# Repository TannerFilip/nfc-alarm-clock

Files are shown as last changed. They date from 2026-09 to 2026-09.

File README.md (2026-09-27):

# NFC-dismiss alarm clock firmware

Milestone 5 development increment: staged PN7160 NCI transport and physical-tag
bring-up. **Production alarms remain gated until the connected reader has passed
the on-device checks below.**
The user confirmed milestone 1 works on-device. Milestone 2 has not been flashed
or physically verified by the agent. The user reports the OLED, encoder/light
sensing and 5% audio test work. The PN7160 board is now connected, but its straps,
VEN/IRQ behavior and NCI communication remain unverified. Milestone 3 builds and
host tests pass; the user reports its development alarm sounded and was dismissed
through the enrolled simulated-tag path on the device.
Milestone 4 builds and host tests pass. The user reports that its QR join and
direct configuration page work, but its remaining persistence/recovery checks
have not been physically observed. Milestone 5 implementation is present; its
host suite and both firmware profiles build successfully. The user reports that
NFC-A reading and explicit physical enrollment now work; remaining results are in
[the validation log](docs/validation.md).

## Build and flash

Pinned SDK: **ESP-IDF v6.1**, commit
`fff9895c82d744c7237be8847347bdd1b07c6643`. No Arduino or external components.
Use Espressif Installation Manager to install v6.1 for ESP32-S3, or the pinned
`.devcontainer` image. In VS Code select that installation with the Espressif
extension, then open an ESP-IDF terminal. Do not use the old root `sdkconfig`:
the original starter targeted ESP32 / 2 MB. Use the isolated build below.

On this workstation the EIM environment can be activated with:

```bash
source /home/tanner/.espressif/tools/activate_idf_v6.1.sh
idf.py --version
```

From the repository root, production profile (simulation disabled):

```bash
idf.py -B build/m1 -D SDKCONFIG=build/m1/sdkconfig build
idf.py -B build/m1 -D SDKCONFIG=build/m1/sdkconfig -p /dev/ttyUSB0 flash monitor
```

Replace `/dev/ttyUSB0` with the USB-to-UART bridge's port; use the DevKit's UART
USB connector. Monitor baud is 115200. Exit monitor with Ctrl+]. If automatic
download fails, hold BOOT, tap RESET, release BOOT, and retry flash. These
commands write bootloader, partition table and application; no erase-flash is
required. Flash only the specified N32R16V module. Do not burn eFuses.

Follow the supplied [hardware power instructions](hardware/breadboard-prototype/README.md):
**disconnect U3 OUT from U1 5V before attaching programming USB**. Remove USB
before reconnecting U3. The boost supply and programming USB must not be connected
to U1 simultaneously under this wiring guide.

Explicit development profile, in a separate configuration/build directory:

```bash
idf.py -B build/m1-dev -D SDKCONFIG=build/m1-dev/sdkconfig -D 'SDKCONFIG_DEFAULTS=sdkconfig.defaults;sdkconfig.development' build
idf.py -B build/m1-dev -D SDKCONFIG=build/m1-dev/sdkconfig -p /dev/ttyUSB0 flash monitor
```

This prints the development/simulation banner on serial and OLED and enables the
Milestone 5 development firmware. The `build/m1` and `build/m1-dev` directory names
are retained for VS Code compatibility; they build the current source.
Never ship the development profile. To use the extension's
Build/Flash buttons instead, the checked-in workspace settings currently select the
development profile: `idf.buildPath` is `${workspaceFolder}/build/m1-dev`, and
`idf.cmakeCompilerArgs` supplies both `-DSDKCONFIG=build/m1-dev/sdkconfig` and
`-DSDKCONFIG_DEFAULTS=sdkconfig.defaults;sdkconfig.development`. Select
the UART port. The CLI commands above are the reference workflow.
These development build settings are already supplied in `.vscode/settings.json`.

## Milestone 5 PN7160 bring-up

Milestone 5 is deliberately staged. It adds a bounded PN7160 NCI 2.0 transport,
initial NFC-A polling and physical tag events through the same `AlarmService`
authorization and durable-dismissal path used by `nfc_sim`. The reader is not an
alarm-state owner: a missing, wedged or reconnecting PN7160 must report a fault
and recover independently without blocking timekeeping, audio or the web UI.

The first physical scope reads NFC-A identifiers only. It does not claim support
for every PN7160 RF technology, cryptographic card authentication or tamper
resistance. Physical enrollment remains an explicit, idle-only, time-limited
operation; presenting a tag during ordinary operation must not silently enroll
it. Until the board checks below pass, production continues to reject enabled
schedules and suppress enabled schedules loaded from development without erasing
them. Use the development profile for alarm tests in the meantime.

Before powering the prototype, confirm the board is the **NFC 7 Click I2C**
variant, VCC SEL is at **3.3 V**, and read both ADDR SEL straps. Both straps at 0
select 7-bit address **0x28**; other supported selections are 0x29-0x2B. Then:

1. Follow the power-isolation rule above, flash the development image and confirm
   the `milestone 5 / 0.5.0` development banner. The generic `i2c_scan` deliberately
   skips 0x28-0x2B because probing is a write that could violate PN7160 IRQ
   sequencing. The device log must report the strap-selected address only after
   successful NCI reset/init and NFC-A discovery.
2. With no tag present, verify normal clock, controls, audio and setup operation.
   Hold an NFC-A tag in the field. Expect bounded, de-duplicated identifier events
   rather than a tight stream; the re-arm interval may permit a later repeat.
3. While idle, run `tag_enroll` or select **Enroll next tapped card** on the setup
   page, present one tag within 60 seconds and confirm the window closes. A tag
   presented outside that window must not be added.
4. Trigger a development alarm. Present an unknown tag and confirm it keeps
   ringing. Present the enrolled physical tag and confirm durable dismissal;
   `alarm_status` must then report no active occurrence.
5. Trigger another alarm, remove power only after its activation is durable, then
   reboot. Confirm it resumes before reader availability is assumed and that only
   the enrolled physical tag dismisses it. Reboot again and confirm it does not
   resurrect.
6. With power off, disconnect the PN7160 and reboot. Confirm an explicit reader
   fault while the clock and active alarm continue. Reconnect only with power off,
   reboot and confirm reset/init/discovery recover. Any supported live recovery
   test must use the documented reader retry path, not energized hot-plugging of
   the prototype.

Full transport rules, expected evidence and known limitations are in
[Milestone 5](docs/milestone-5.md). These are manual acceptance steps, not claims
that the board has already passed them.

## Milestone 4 local setup acceptance

Milestone 4 stores validated settings and the alarm journal separately in NVS.
While the clock is idle, hold Button 2 for three seconds. The OLED shows a
time-limited Wi-Fi join QR code and setup URL. Scan the code with a phone camera,
join the network and browse to `http://192.168.4.1/`; the configuration page opens
directly with no second setup code. Button 1 switches between the QR screen and a
text fallback containing the SSID and 12-character password.
The generated credentials use an alphabet without ambiguous glyphs and are never
written to the serial log. The page has no external assets and the AP expires
after 15 minutes.

Use the development profile for enabled-alarm testing until physical PN7160
dismissal passes Milestone 5 acceptance. Production accepts general settings but
rejects enabled schedules and suppresses any enabled development schedules found
in NVS without erasing them. Full reboot, access-control, expiry and recovery checks are in
[Milestone 4](docs/milestone-4.md).

## Development alarm/simulation regression

Use only the development profile for this simulated-dismissal regression. Its
schedule, timezone, enrolled tags and journal persist in NVS; the production
profile does not contain the serial mutation/simulation commands and still rejects
enabled schedules pending physical acceptance. Set valid UTC, arm physical
enrollment and tap the card to use for the test, then configure the alarm:

```text
tag_enroll
alarm_zone America/Los_Angeles
alarm_set 07:00 0111110
alarm_status
alarm_trigger
```

The weekday mask is Sunday through Saturday, so `0111110` means Monday-Friday.
Use an alarm time one or two minutes ahead to test normal scheduled firing.
`alarm_trigger` is a development shortcut but enters the same ringing state.
Expect a repeating 440 Hz tone that ramps from 1% to 5% digital peak over 30
seconds and an `ALARM RINGING` OLED warning.

While ringing, buttons and the encoder may change diagnostic pages/brightness but
must not dismiss the alarm. `clock_set`, `audio_test`, `alarm_set`, `alarm_zone`,
tag enrollment and another trigger must be rejected or have no bypass effect.
An unknown simulated tag must leave it ringing:

```text
nfc_sim AABBCCDD
alarm_status
```

For the simulated half of this regression, replace `ENROLLED_UID` with the
identifier logged for the physically enrolled card. It must take the identical
authorization path and stop the alarm only after its dismissal is accepted by the
journal:

```text
nfc_sim ENROLLED_UID
alarm_status
```

Flash the production profile afterward and confirm `help` has no `nfc_sim`,
`alarm_set`, `alarm_zone`, or `alarm_trigger` command and no simulator OLED
banner. `tag_enroll` remains present because it arms the physical reader only.
Historical Milestone 3 policy boundaries are in [Milestone 3](docs/milestone-3.md).

## Remaining Milestone 2 manual acceptance

Follow the power/flash instructions above. Open the UART console at 115200 baud.
Type `help` at `clock>` to list commands. Press Enter if periodic status logging
has displaced the prompt. Each command queues work; the log reports its result.

1. Check the current milestone **5 / 0.5.0** development banner and `memory=OK` (33554432 bytes flash,
   16777216 bytes PSRAM). Production must report simulation disabled; development
   must show a development/simulation warning on serial and OLED.
2. Run `i2c_scan`. Expect ACKs at **0x23, 0x36, 0x3C, 0x68** for the installed
   modules. An ACK does not prove identity; missing devices are reported separately.
   The scan deliberately skips 0x28-0x2B; use the PN7160 driver's separate
   address and reset/init/discovery status as the functional check.
3. Run `clock_status`. Check the OLED is legible in landscape, with no clipped or
   shifted lines. An unset RTC should show an invalid-time message, not a guessed
   clock. The default display uses UTC; timezone support comes with scheduling.
4. Set the actual current UTC time using the format below (replace the example):

   ```text
   clock_set 2026-09-19T22:00:00Z
   clock_status
   ```

   Expect a running OLED clock and RTC status `OK` (or an explicit battery fault).
   Dates outside 2000–2099 and malformed/impossible dates are rejected. Without an
   RTC, manual time works in RAM and is explicitly reported as not written to RTC.
   With its backup coin cell installed, remove MCU/main power for a minute, then
   reconnect using the wiring guide's power procedure. Time should have advanced
   and source should be `RTC`. If the oscillator was stopped, allow two seconds
   and set UTC again if its validity flag persists.
5. Rotate the encoder: clockwise should increase contrast and counterclockwise
   decrease it. Press the encoder or button 1 to alternate clock/status pages.
   Button 2 prints status only. Each press/release should appear once in the log;
   none of these controls dismiss an alarm or start sound.
6. Run `brightness 20`, then `brightness 120`. Run `ambient on`, shade/uncover the
   BH1750 and check contrast follows coarse light bands up to the manual ceiling.
   `ambient off` restores manual contrast. These settings are RAM-only and reset
   on reboot. Missing light readings fall back to manual brightness.
7. Compare `battery_mV` with a multimeter on the battery terminal. ADC calibration
   is from the ESP32 eFuses, with nominal divider factor 2; resistor tolerances and
   board accuracy still need checking. `-1` means unavailable. If calibration is
   unavailable, only raw ADC counts are reported. No percentage is estimated.
8. With the amplifier powered from LOAD OUT and the speaker wired as documented,
   explicitly run `audio_test`. Expect one **two-second 440 Hz tone**, 1% digital
   peak with 100 ms fade-in/out, then silence. Try another request during playback:
   it should be rejected as busy, not extend the tone. Try `clock_status` and
   controls during playback. The test drives both I2S channels equally; digital
   amplitude is not a calibrated acoustic level. SD is not controlled by firmware.
   If the 1% tone is inaudible after checking supply/SD voltage, speaker resistance
   and wiring, run `audio_test 5` for a two-second test at 5% digital peak. Only
   levels `1` and `5` are accepted; no argument retains the original quiet 1% test.
   Wait for completion before another test. The extra I2S log describes configured
   pins/clock rates, not measurements at the amplifier.
9. With power off, disconnect one peripheral and reboot. Confirm a clear missing
   status and continued operation of unrelated controls/console/audio. Restore
   wiring with power off and reboot; verify recovery. The drivers also retry I2C
   faults at five-second intervals, but do not hot-plug an energized prototype.

For additional expected results, reference protocols, and limitations, see
[the milestone 2 handoff](docs/milestone-2.md).

## Automated checks

```bash
python3 tools/check_build.py build/m1
python3 tools/check_build.py build/m1-dev --development
cmake -S tests -B build/host
cmake --build build/host
ctest --test-dir build/host --output-on-failure
```

A memory mismatch logs a fault. Missing PSRAM remains allowed for diagnostics,
but is a failed hardware acceptance check. Compilation and host tests do not
validate physical wiring, OLED orientation, audio output or RTC battery retention.

See [architecture and policies](docs/architecture.md),
[hardware evidence](docs/hardware.md), [validation](docs/validation.md), and
[future features](docs/backlog.md).

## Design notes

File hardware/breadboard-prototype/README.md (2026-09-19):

# NFC alarm clock — breadboard prototype

Open `NFC_Alarm_Prototype.kicad_pro` in KiCad, then its schematic. The PDF is a printable A3 wiring drawing. `wiring.csv` lists every represented terminal. Keep `Prototype.kicad_sym` and `sym-lib-table` alongside the project.

This is a functional module wiring diagram. Module pin identifiers follow the board labels, not the underlying IC pin numbers or physical header order. Unused headers and onboard circuitry are omitted. The PCB file is blank; this project is not ready for fabrication.

## Parts represented

| Reference | Part |
|---|---|
| U1 | Espressif ESP32-S3-DevKitC-1-N32R16V |
| U2 | Adafruit 4755 BQ24074 charger with power path and USB-C |
| U3 | Adafruit 4654 TPS61023 MiniBoost, nominal output 5.2 V |
| BT1 | Protected 1S LiPo, 3.7 V nominal / 4.2 V full, 1200 mAh; Adafruit 258 proposed |
| U4 | Adafruit 3006 MAX98357A I2S amplifier |
| LS1 | Same Sky CMS-4012-34L200-X7, 4 ohm / 3 W speaker |
| C1 | Panasonic EEU-FR1E221B, 220 uF / 25 V polarized capacitor |
| U5 | Adafruit 4650 128x64 SH1107 OLED FeatherWing |
| U6 | Adafruit 5189 PCF8523 RTC breakout; separate CR1220 in its onboard holder |
| U7 | Adafruit 4681 BH1750 light sensor |
| U8 | Adafruit 5880 seesaw rotary encoder with push switch |
| U9 | Proposed MikroE MIKROE-6453 NFC 7 Click I2C, PN7160 |
| SW1, SW2 | Omron B3F-1020 push buttons |
| R1, R2 | 100 kohm each |
| C2 | 100 nF ceramic |

U9 is a proposed selection, not a confirmed substitution from the shopping cart. This pinout applies specifically to the NFC 7 Click **I2C** board. Its mikroBUS pin 16 (PWM) controls VEN, and pin 15 (INT) carries IRQ. Pin 2 (RST) belongs to ClickID and is not PN7160 reset. Use the board's 3.3 V selection, leave its 5 V terminal unused, and check its address straps against the firmware.

## Power and assembly

- Plug a suitable 5 V USB supply into U2's own USB-C connector. A separate USB-C breakout is unnecessary here.
- Connect the protected 1S battery to U2's battery connector, checking polarity. Set the charger to 500 mA using its documented charge-current jumper configuration; do not leave a higher setting without checking the battery's charge rating.
- `VBUS` is USB input. `+BATT` is the battery terminal. `VCC` is the charger LOAD OUT, approximately 3–4.4 V. These are separate nets.
- Feed U3 IN from LOAD OUT and tie EN to IN. `+5V` denotes U3's nominal 5.2 V output, feeding U1's 5V terminal. U1's regulator supplies the `+3V3` rail.
- Before attaching a programming USB cable to U1, disconnect U3 OUT from U1 5V. Reconnect after removing that cable. Follow the DevKit's power-source restrictions.
- Feed the amplifier from LOAD OUT. Fit C1 near its VIN/GND, observing capacitor polarity. Tie GAIN to VIN for 6 dB; leave SD open to use this breakout's default mono mix. Neither speaker lead connects to ground.
- All grounds are common. Keep the NFC antenna away from metal, the speaker, and switching-power wiring. Keep speaker and supply jumpers short. Existing module decoupling is not repeated in the diagram.
- The modules supply I2C pull-ups. Start at 100 kHz with short wiring; inspect the combined pull-up resistance and signal edges if communication is unreliable. All bus logic is 3.3 V.
- Check the combined 3.3 V load and regulator temperature with Wi-Fi transmitting and the NFC field active. This schematic does not prove current margin, RF performance, or runtime; those need a powered prototype test.

## Firmware pin map

| GPIO | Function |
|---|---|
| 1 | Battery ADC through R1/R2; maximum 2.1 V at full charge |
| 5 | I2S BCLK |
| 6 | I2S LRCLK / LRC |
| 7 | I2S data to amplifier |
| 8 | Shared I2C SDA |
| 9 | Shared I2C SCL |
| 10 | OLED reset |
| 11 | SW1, internal pull-up |
| 12 | SW2, internal pull-up |
| 15 | PN7160 IRQ input |
| 16 | PN7160 VEN output |

Configure the N32R16V's octal flash and PSRAM correctly. The GPIO interface is still 3.3 V. Configure ADC attenuation for the divider range and calibrate readings; the divider measures the battery, not LOAD OUT.

The OLED uses an SH1107 driver (Adafruit SH110X), default address 0x3C, and a startup reset pulse. Its extra buttons are unused. PCF8523 uses 0x68, BH1750 0x23, and seesaw 0x36. Poll the encoder's push switch through seesaw. The basic prototype keeps the MCU awake and handles alarm timing in software using the RTC; SQW and encoder INT remain open. RTC-triggered deep sleep is not implemented by this wiring. PN7160 requires a compatible NCI software stack, not a PN532 driver.

## Validation

KiCad ERC completed with **0 errors and 0 warnings**. Konnect found no floating wire ends, unconnected represented pins, orphan items, shorted named nets, or overlapping symbol geometry. Every intended signal and supply connection was compared with the exported netlist, including the battery divider and isolated speaker outputs. The drawing was rendered and visually reviewed. These checks validate the represented wiring, not module internals or physical hardware performance.

## Manufacturer references

- [ESP32-S3 DevKitC-1 guide](https://docs.espressif.com/projects/esp-dev-kits/en/latest/esp32s3/esp32-s3-devkitc-1/user_guide.html)
- [Adafruit BQ24074 charger](https://www.adafruit.com/product/4755)
- [Adafruit MiniBoost](https://www.adafruit.com/product/4654)
- [MAX98357A breakout pinouts](https://learn.adafruit.com/adafruit-max98357-i2s-class-d-mono-amp/pinouts)
- [OLED FeatherWing](https://www.adafruit.com/product/4650)
- [PCF8523 breakout](https://www.adafruit.com/product/5189)
- [BH1750 breakout](https://www.adafruit.com/product/4681)
- [Seesaw encoder](https://www.adafruit.com/product/5880)
- [NFC 7 Click I2C](https://www.mikroe.com/nfc-7-click-i2c)

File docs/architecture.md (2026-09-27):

# Architecture and incremental delivery

Milestones 1-4 are implemented. Milestone 5 is a staged physical PN7160
integration and remains a development increment until device acceptance.
Milestone 2 has partial user-reported physical
verification, including audible output at 5%; remaining acceptance is documented
in `docs/validation.md`.
`main/drivers/` contains I2C, RTC, controls, display, sensing and audio bring-up.
`main/core/` contains portable calendar, alarm, scheduling, tag and control helpers.
`alarm_service.cpp` owns alarm state on a dedicated task; `bringup.cpp` integrates
bounded command events. Validated NVS and a time-limited SoftAP/web UI are integrated;
the physical NFC transport is the current work.

| Module | Responsibility |
| --- | --- |
| `alarm_core` | Hardware-independent C++ state machine; schedule occurrences, active set, tag authorization; no IDF calls |
| `timekeeping` | UTC system clock, PCF8523 UTC backing, explicit validity, POSIX timezone conversion, manual setting, optional SNTP |
| `configuration` | Validated versioned settings and enrolled tags in NVS; atomic durable alarm journal; no writes per tick |
| `audio` | Dedicated I2S DMA task, monotonic volume ramp and bounded idle-only audio test; no SD control |
| `i2c_bus` | Single owner/serialized transactions with finite deadlines; peripheral failures and recovery backoff |
| `display_controls` | SH1107 rendering, seesaw polling and debounced buttons; emits intent events |
| `nfc` | Reader interface emits bounded tag IDs/status; production PN7160 NCI transport; separate development simulator |
| `web_wifi` | Local HTML/CSS/JS assets, validated configuration requests, deliberate time-limited SoftAP; no STA/LAN listener yet |
| `sensing` | BH1750 lux/dimming and calibrated ADC voltage; divider factor 2, no invented battery percentage |
| `main` | Integration, bounded queues and status; persistence, setup and staged PN7160 integration |

The alarm task owns state. Hardware, NFC and web tasks submit typed events through
bounded queues. Scheduling and audio never wait for network or NFC. I2C requests
have deadlines (initial target 20 ms per transfer), with IRQ/NFC waits outside
the bus lock. Time-critical state and DMA buffers use internal RAM. Missing
peripherals are explicit status faults, not global startup failures. No confirmed
RTC time means unsynchronized status, not a fabricated current time.

## Alarm policies implemented in the Milestone 3 core

The portable core implements these rules behind an abstract journal. Host tests
exercise recovery and injected journal failures. Firmware 0.4.0 connects the same interface to a checksum-protected NVS journal
and loads a separate validated settings record before journal recovery. Development
simulation commands remain compiled out of production.

- States: `time_invalid`, `idle`, `ringing`, plus orthogonal device/storage faults.
  A restored active occurrence rings even when wall-clock time is invalid.
- Each occurrence has a stable alarm ID and local calendar date, stored with its
  UTC due time. Persist the active set before starting sound. Record dismissal
  durably before silence; failed persistence keeps ringing and reports a fault.
  Power loss between durable dismissal and audio stop must not resurrect it.
- On reboot, resume every persisted active occurrence with a short volume ramp.
  Never infer dismissal from boot, time changes or configuration edits. Journal
  corruption is a visible recovery fault, never silently treated as empty.
- Missed alarms: when valid time resumes, catch up occurrences at most 5 minutes
  late; record older ones as missed for status, without ringing. First setup does
  not retroactively ring. The journal retains a UTC evaluation cursor, a saturating
  missed counter and the most recent 32 occurrence keys FIFO; the cursor prevents
  replay after older history expires or backward clock adjustments. Occurrence,
  dismissal, missed and skipped changes commit immediately; an otherwise-idle
  cursor checkpoints at most once per five minutes rather than once per tick.
- Overlaps join one active set and one audio stream. One enrolled tag scan
  dismisses all occurrences active at that instant. A later occurrence is new.
- DST spring gap: skip the nonexistent local time and report it as skipped. DST
  fall fold: fire only the first occurrence of the selected local time that date.
  Weekdays refer to the configured local calendar, not UTC.
- Milestone 3's curated zones are UTC and `America/Los_Angeles`. The latter uses
  the applicable US DST transition rules for 2000-2099, including the 2007 rule
  change. Additional curated zones require their own transition tests.
- Timezone/manual-time edits affect future scheduling only. Forward changes use
  the missed-alarm window; backward changes never replay recorded occurrences.
  Freeze each ringing occurrence and its enrolled-tag authorization snapshot.
- While ringing, buttons, encoder and configuration cannot dismiss, disable the
  audio path, lower its captured maximum volume, delete its authorization snapshot,
  or initiate a reset/setup/audio-test operation that bypasses dismissal. Reject
  incompatible writes with a visible error; do not silently accept and ignore them.
- Production will accept only physical enrolled tag events once that reader exists;
  it currently exposes no tag path. Development injection uses
  the same authorization/state path, requires both build flags, and will carry
  conspicuous OLED/web badges. Unknown tags never dismiss. Enrollment is allowed
  only while idle through authenticated, time-limited explicit enrollment mode.

Tag identifiers are not cryptographic authentication. Removing power stops the
hardware; the clock is not tamper-proof. Battery duration remains a physical test.

## Configuration and access implementation (milestone 4)

Firmware 0.4.0 uses schema-versioned, size-bounded NVS records with validation for names, alarm count,
weekday masks, times, timezone syntax, tag lengths/count, volume and brightness.
Reject unsupported schema versions without erasing data. Write only changed
settings; separate settings from the low-frequency occurrence journal.

Keep RTC in UTC; expose explicit valid/invalid/stale status and synchronization
source. Use a curated timezone list mapping to tested POSIX TZ rules (IDF does
not ship a full IANA zone database). Manual setting remains available offline.

A three-second Button 2 hold while idle opens a 15-minute WPA2 SoftAP with
per-start credentials displayed only on the OLED as a Wi-Fi join QR with a
Button 1 text fallback. The QR dependency is exact-pinned, and its
credential-bearing payload is encoded with the component log tag temporarily
suppressed. The local HTTP UI is confined to that AP and uses bounded requests
and rate, a per-start CSRF token, and exact Host/Origin checks. The WPA2 password
is the only user-entered setup credential. There is no LAN listener or external
asset.
HTTPS and STA provisioning remain future work. Wi-Fi shutdown never changes alarm
state, and setup stops if an alarm begins.

## PN7160 transport and reader policy (Milestone 5)

The PN7160 adapter uses portable NCI frame/parser helpers and an ESP-IDF transport
state machine on the shared `i2c_bus`. The initial RF scope is passive
NFC-A polling and extraction of bounded NFCID1 values. Other RF technologies,
peer-to-peer, card emulation and cryptographic card authentication are outside
this increment.

- VEN boot, CORE_RESET, CORE_INIT, explicit ISO-DEP discovery mapping, discovery,
  target selection and activation advance through a bounded, monotonic state
  machine. All command/response waits have deadlines and failures enter delayed
  retry rather than a tight loop.
- IRQ is the read-ready signal. Firmware never holds the shared I2C lock while
  waiting for IRQ, never performs a speculative read while IRQ is inactive, and
  does not start a command write while unread IRQ data is pending. Each actual
  transfer retains the bus's finite deadline.
- NCI frames are carried as-is over I2C, without a private header or CRC. Receive
  handling bounds the three-byte NCI header and payload before parsing. A failed
  write retries the whole frame only through the reader recovery policy.
- Reader faults and reinitialization are orthogonal to alarm state. They may
  change NFC availability/status, but cannot dismiss, silence, clear or delay an
  active occurrence; timekeeping, audio, controls and web processing continue.
- A physical NFCID1 becomes the existing bounded `TagId` event and enters through
  `AlarmService::submit_physical_tag`; normal operation then uses the same
  `AlarmCore::handle_tag` authorization path as development simulation.
  There is no physical-reader bypass around the frozen authorization snapshot or
  durable dismissal journal. Unknown and malformed identifiers do not dismiss.
- A continuously held tag is de-duplicated until removal/deactivation or a
  bounded 1.5-second re-arm interval; event flooding must not starve the alarm
  queue, and a rejected callback submission is retried rather than counted as
  delivered.
- Enrollment is a separate, conspicuous, idle-only and time-limited mode. Normal
  discovery never mutates enrolled tags. Enrollment must persist settings before
  reporting success, and it closes on timeout, successful enrollment or alarm
  start. A reader fault does not extend the window: its original 60-second timeout
  still bounds it. The console and temporary setup page expose the initial flow;
  a dedicated OLED interaction remains a possible refinement.

The production enabled-alarm gate remains in place until the delivered board's
I2C variant, 3.3 V selection, address straps, VEN/IRQ behavior, NCI reset/init,
tag discovery and enrolled/unknown dismissal behavior have been validated on the
device. Compiling the driver or seeing an I2C ACK is not sufficient to remove the
gate.

## Delivery gates

1. **Built; user reports hardware working:** pinned build, memory/boot logging, architecture, flash instructions.
2. **Built; partially user-tested:** Shared I2C discovery and fault status; OLED, RTC, seesaw, buttons; explicit
   bounded low-volume I2S test; voltage and light sensing. Validate each on-device.
3. **Built, host-tested and user-tested:** Portable core and simulator: host tests for scheduling, weekdays, DST gaps/folds,
   forward/backward clock changes, recovery, overlap, unknown/valid tags and bypass
   attempts. Fault-inject journal writes. Compile both development and production.
4. **Built and host-tested; partially user-tested:** deterministic settings
   validation/codec, checksum-protected NVS settings and journal, and bounded
   WPA2-protected local setup UI. The user reports QR join and direct
   configuration work; exercise reboot recovery, access control, bad requests,
   expiry and disconnection during alarm on-device.
5. **Current development increment; validation pending:** staged PN7160 NCI transport
   and NFC-A reads. Verify straps/address/voltage, controller reset/init, held-tag
   de-duplication, explicit enrollment, known/unknown dismissal, active reboot
   recovery and disconnected-reader recovery before enabling production alarms.

Every gate gets its own recorded build/test results and exact flash/manual tests.
Successful compilation never marks a hardware gate passed.

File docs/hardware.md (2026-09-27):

# Hardware evidence and unresolved checks

Inspected 2026-09-19 before firmware edits. The workspace initially had only an empty IDF C
starter, ESP32/2 MB generated configuration, VS Code and container files; no wiring
guide, schematic or project README. No AGENTS.md was found in the workspace.
The user subsequently supplied `hardware/breadboard-prototype/`, which is now
the authoritative reference. Read its README, wiring.csv and exported
netlist-summary.json. The wiring guide and exported netlist agree with the GPIO
table, amplifier connections, NFC pinout and battery divider in the request.
No hardware files were modified. The hardware README's old project filename
`NFC_Alarm_Prototype.kicad_pro` is stale; the supplied file is named
`breadboard-prototype.kicad_pro`. This is a documentation naming issue only.

Located `/home/tanner/Documents/NFC_Alarm_Prototype.zip`; read its existing
`netlist-summary.json`, not edited schematic source. U1 matches every requested
GPIO. U4 confirms GAIN and VIN both on VCC and SD unconnected; R1/R2 are 100k and
C2 is 100nF. U9 confirms PWM/VEN and INT/IRQ. The separate
`/home/tanner/Alarm-Clock/Alarm-Clock.kicad_sch` exported an empty netlist, so it
cannot establish wiring. All original hardware files/archive remain untouched.
The supplied hardware directory supersedes that initial archive lookup.
No firmware peripheral pins are driven in milestone 1.

| Function | GPIO / address from request, corroborated GPIO netlist |
| --- | --- |
| I2C SDA/SCL | 8 / 9 |
| SH1107 reset | 10; expected 7-bit address 0x3C |
| PCF8523 | expected 0x68 |
| BH1750 | expected 0x23 |
| seesaw encoder | expected 0x36; INT not connected, poll |
| MAX98357A BCLK/LRCLK/DIN | 5 / 6 / 7; no MCU SD pin |
| Buttons to ground | 11 / 12, internal pull-ups |
| Battery ADC | 1, 100k/100k and 100nF, 2.1 V max input |
| PN7160 IRQ/VEN | 15 / 16; mikroBUS INT / PWM |

No GPIO discrepancy was found against the prototype exported netlist. Peripheral
addresses above are expectations, not device identities established by probing.

## Manufacturer checks

- [Espressif board table](https://documentation.espressif.com/esp-dev-kits/en/latest/esp32s3/esp32-s3-devkitc-1/user_guide_v1.0.html):
  N32R16V is WROOM-2 with 32 MB octal flash and 16 MB octal PSRAM, 1.8 V memory
  interface. This is not the external 3.3 V peripheral logic voltage.
- [Memory configuration](https://docs.espressif.com/projects/esp-idf/en/latest/esp32s3/api-guides/flash_psram_config.html):
  use octal flash DTR 80 MHz and octal PSRAM 80 MHz, with PSRAM autodetection and
  boot memory test. Firmware compares detected capacities. IDF's image header may
  say `dout`: its OPI configuration deliberately encodes that boot header value;
  `CONFIG_ESPTOOLPY_OCT_FLASH` and `FLASHMODE_OPI` select actual octal operation.
  Factory memory voltage/eFuses are not modified.
- [ESP-IDF v6.1 release](https://github.com/espressif/esp-idf/releases/tag/v6.1):
  stable release matching the installed SDK; use native IDF APIs, no Arduino
  compatibility dependency. API declarations checked against the installed SDK.
- [MIKROE NFC 7 I2C](https://www.mikroe.com/nfc-7-click-i2c): I2C variant
  PN7160A1HN/C100, VCC SEL must be 3.3 V; ADDR SEL jumpers default both 0 and
  I2C interface resistors must be populated. PWM is VEN; INT is IRQ; RST belongs
  to ClickID. [NXP UM11495](https://www.nxp.com/docs/en/user-manual/UM11495.pdf)
  specifies 7-bit addresses 0x28–0x2B. Both address straps 0 imply **0x28**;
  0x50/0x51 are write/read address bytes, not 7-bit driver addresses. Inspect
  the delivered board's straps and confirm NCI communication before selecting
  its final address. PN7160 uses NCI 2.0; a PN532 driver is not interchangeable.

For Milestone 5, the PN7160 is an I2C follower. NCI packets are transferred
without an additional host header or CRC and are bounded to 258 bytes including
the three-byte NCI header. IRQ is the read-ready indication: do not issue a read
until IRQ is active, and drain pending IRQ data before a command write. Header and
payload may be read in split transactions, but every transaction must use the
shared serialized bus and a finite deadline. Waiting for IRQ or VEN boot never
holds the bus. On an I2C write NACK, resend the complete NCI frame only through a
bounded reset/backoff path rather than continuing from a partial offset.

Before milestone 2: confirm board marking, actual I2C pull-ups and
addresses, OLED reset routing, and power arrangement. Before battery tests,
confirm the actual battery/power-path assembly and measure voltage at GPIO1.

## PN7160 arrival status (user report, 2026-09-27)

The user reports that the NFC board is now connected. No photo, I2C scan, strap
reading, IRQ/VEN trace or NCI exchange has been supplied, so this does not yet
confirm the I2C variant, 3.3 V selection, 0x28-0x2B address, or functional reader.
Milestone 5 development is introducing GPIO15/16 control and NCI commands. An
I2C scan ACK, if present while the module is enabled, establishes only a responder
at that address. Physical acceptance must independently verify VEN sequencing,
the default active-high IRQ behavior, NCI reset/init and NFC-A discovery against
the delivered board. None of those checks has yet been supplied or agent-observed.

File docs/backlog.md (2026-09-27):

# Future features

Requested by the user after milestone 1 hardware confirmation. These are planning
items, not implemented capabilities or instructions to change hardware now.

## Battery charge limit

Aim to keep the battery around 80% during normal plugged-in use, while retaining
enough energy to carry the clock to the NFC tag. Hardware changes may be needed.
Before implementation, review charger control options, power-path behavior and
state-of-charge measurement against manufacturer documentation. Do not equate
an uncalibrated voltage threshold with an accurate 80% charge level. Define the
charge/resume policy and failure behavior before selecting hardware or firmware.

## Occasional Wi-Fi time synchronization

Extend the planned optional network synchronization into periodic time updates.
Keep RTC-backed operation independent of network availability. Choose the interval,
connection/retry budget and clock-correction policy during timekeeping integration;
expose the last successful sync and time validity. Corrections must obey the
documented missed-alarm and duplicate-occurrence policies.

## Deliberate backup dismissal

Provide an alternative if NFC dismissal is unavailable. Candidate approaches are
a recessed/pinhole physical button or an authenticated webpage requiring a
physical action, potentially checked through the phone's sensors. A simple web
"stop" button does not satisfy the user's intent.

The mechanism and required action are undecided. Before implementation, define
what physical effort/presence is intended, how activation works while ringing,
and how accidental use is prevented. For a phone-based option, investigate actual
browser sensor support, permissions, secure-context requirements and the limits
of treating client-reported sensor events as evidence. Do not promise sensor
availability or tamper resistance without verification.

Once selected, document this as an explicit exception to NFC-only dismissal in
the architecture and agent instructions. Route it through the alarm state machine
and durable dismissal journal, with tests for authorized use and bypass attempts.
Until then, preserve the current NFC-only production policy and development-only
simulation gate. Ordinary controls/configuration must never silently dismiss.

## Physical tag enrollment UX

Milestone 5 introduces a narrow 60-second enrollment window through `tag_enroll`
and the temporary setup page. The final on-device interaction and review remain a
design task. Enrollment must stay explicit, conspicuous and idle-only; normal
background scans must never add a tag. The flow must report the identifier stored,
reject duplicate/invalid identifiers, persist settings before confirming success,
and cancel on timeout or alarm start. A reader fault must not extend the original
60-second timeout. After the basic reader
transport passes device validation, decide whether to add a deliberate physical
control gesture and how the OLED should expose the active window.

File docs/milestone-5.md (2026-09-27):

# Milestone 5: staged PN7160 physical integration

Firmware 0.5.0 is a development increment for the connected PN7160 board. Its
purpose is to establish a bounded NCI 2.0 transport, passive NFC-A discovery and
the physical-tag path into the existing alarm authorization logic. The
implementation is present, the five-executable host suite passes, and both firmware
profiles build successfully. Every physical result remains pending unless recorded in
`docs/validation.md`.

## Scope and safety gate

This increment initially supports NFC-A identifiers only. It does not implement
all PN7160 technologies, tag data exchange, card emulation or cryptographic card
authentication. An NFCID is an identifier, not proof that a tag cannot be cloned.

Production enabled alarms remain gated until the delivered board passes the full
manual acceptance below. The development profile retains `nfc_sim`, but simulated
and physical events must both call the same bounded tag submission and
authorization path. Neither path may directly silence audio or edit the alarm
journal.

Physical enrollment is separate from ordinary discovery: `tag_enroll` or the
setup page's **Enroll next tapped card** action starts a 60-second window while
idle. It ends on success, timeout or alarm start. A reader fault does not
explicitly cancel it, but cannot extend the original 60-second timeout. An
ordinary tag presentation never silently enrolls a tag. Do not remove the
production gate merely because identifier reads work.

## Transport policy

- GPIO16 drives PN7160 VEN and GPIO15 reads IRQ. The Click board's RST signal is
  ClickID, not PN7160 reset, and is not substituted for VEN.
- Boot, CORE_RESET, CORE_INIT, ISO-DEP discovery mapping, RF discovery,
  `RF_DISCOVER_SELECT` and activation form a monotonic, deadline-bounded state
  machine with delayed retry. The driver drains `MORE` discovery notifications,
  selects a supported final NFC-A candidate, and accepts the UID only from its
  activation notification. No unbounded wait, task spin or recursive retry is allowed.
- The driver waits for IRQ without owning the shared I2C mutex. It reads only when
  IRQ is active and drains pending response/notification data before writing a
  command. Each bus transaction keeps the existing finite transfer deadline.
- NCI's three-byte header and declared payload length are validated before any
  message-specific parse. NCI frames travel directly over I2C with no extra
  length prefix or CRC. A failed write restarts the complete frame through bounded
  recovery.
- Malformed, oversized, unexpected or timed-out frames cause explicit status and
  reader recovery; they do not change alarm state. Reader absence or restart must
  not block the alarm owner, audio task, timekeeping, controls or web UI.
- A valid NFC-A NFCID1 is converted to the existing bounded `TagId` and queued to
  `AlarmService::submit_physical_tag`, which routes normal scans to the same
  `AlarmCore::handle_tag` authorization used by simulation. Unknown tags remain non-dismissing. Repeated reports
  from one continuously held tag are limited by a 1.5-second re-arm interval. If
  the bounded callback queue rejects a submission, the driver retries rather than
  treating that identifier as delivered.

## Before flashing

With power removed, inspect the actual board:

1. Confirm it is the **NFC 7 Click I2C** variant using PN7160A1HN/C100.
2. Confirm VCC SEL is set to **3.3 V** and the I2C option/resistors are populated.
3. Record both ADDR SEL straps. `0/0` selects 7-bit `0x28`; the supported range is
   `0x28`-`0x2B`. Do not enter the eight-bit wire bytes `0x50/0x51` as addresses.
4. Confirm mikroBUS INT reaches GPIO15 (IRQ) and PWM reaches GPIO16 (VEN). Do not
   treat the RST/ClickID connection as PN7160 reset.

For every programming session, **disconnect U3 OUT from U1 5V before connecting
programming USB**. Remove USB before reconnecting U3. Never power U1 from the boost
output and programming USB simultaneously under the prototype wiring guide.

## Build and automated checks

Use the pinned ESP-IDF v6.1 environment from the repository root:

```bash
source /home/tanner/.espressif/tools/activate_idf_v6.1.sh
idf.py --version
idf.py -B build/m1 -D SDKCONFIG=build/m1/sdkconfig build
python3 tools/check_build.py build/m1
idf.py -B build/m1-dev -D SDKCONFIG=build/m1-dev/sdkconfig -D 'SDKCONFIG_DEFAULTS=sdkconfig.defaults;sdkconfig.development' build
python3 tools/check_build.py build/m1-dev --development
cmake -S tests -B build/host
cmake --build build/host
ctest --test-dir build/host --output-on-failure
git -c core.whitespace=cr-at-eol diff --check
```

Current host coverage includes NCI header/payload bounds, malformed frames,
exact command bytes, response matching/status, valid NFC-A identifier lengths and
irrelevant technology/interface messages. The IDF driver state machine, timeouts,
recovery and held-tag rate limiting are compile-tested but still require the
physical exercises below. Host tests and successful firmware compilation do not validate electrical selection,
VEN/IRQ timing, antenna behavior or an actual RF read.

## Physical acceptance

Flash the development profile first, following the power rule above. Capture a
complete serial log rather than reporting only the final screen.

1. Confirm the `milestone 5 / 0.5.0` development banner, expected flash/PSRAM and
   development warning. Run `i2c_scan` for the non-NFC peripherals. It deliberately
   skips 0x28-0x2B because a probe is a write that may violate PN7160 IRQ ordering;
   compare the address identified by a valid NCI response with the recorded straps.
2. Confirm logs/status separately show VEN boot, NCI CORE_RESET response,
   CORE_INIT response and active NFC-A discovery. Record the selected 7-bit
   address and any status/error bytes. IRQ must be inactive while idle and become
   readable when the controller has a response/notification.
3. With no tag, exercise the clock display, encoder/buttons, `clock_status`, web
   setup and an idle `audio_test 5`. Reader polling must not delay or break them.
4. Present one NFC-A tag briefly. Confirm a bounded identifier event reaches the
   normal tag path. Hold it in the field for at least ten seconds and confirm the
   de-duplication/re-arm interval prevents a tight queue/log flood. Remove it,
   wait for discovery to re-arm, and present it again; a new event should then be
   accepted.
5. While idle, run `tag_enroll` or select **Enroll next tapped card** on the setup
   page. Present one tag within 60 seconds and confirm durable settings acceptance. Repeat
   without enrollment mode and confirm the stored tag set does not change. Let a
   second window expire and confirm a late scan is not enrolled.
6. Trigger a development alarm. Present a different, unknown tag and verify audio
   continues and `alarm_status` remains ringing. Present the enrolled physical
   tag; verify durable dismissal occurs before audio stops and active count becomes
   zero. Buttons, encoder, setup/configuration and reader recovery must not bypass
   this path.
7. Trigger again and remove power only after the active occurrence is durable.
   Reboot and verify ringing resumes independently of reader initialization.
   Present an unknown tag, then the enrolled tag. Reboot once more and verify the
   dismissed occurrence does not return.
8. Power down, disconnect the PN7160, then boot. Confirm an explicit unavailable/
   retrying status while the clock, UI and alarm audio remain functional. Power
   down before reconnecting it, reboot, and confirm reset/init/discovery recover.
   Do not hot-plug this energized breadboard to simulate a fault.
9. Repeat the enabled-alarm, unknown-tag and enrolled-tag checks with the production
   profile only after all preceding evidence passes and the production gate is
   deliberately removed in a reviewed change. Confirm production still contains
   no `nfc_sim` or development-only mutation commands.

## Acceptance status

| Check | Result |
| --- | --- |
| Portable NCI parser/session tests | PASS; host CTest suite 5/5 |
| Production firmware build/checker | PASS; app `0xf5cf0`, SHA-256 `9b528526381ddd293d13c8451557de12d28421455f52aa41706dc1ccf77c1a20` |
| Development firmware build/checker | PASS; app `0xf6080`, SHA-256 `e2a972449dceaf8445eca080e9aa7c5d2078effeb92fa8704acd32f20806f0b9` |
| I2C variant, 3.3 V selection and straps inspected | PENDING |
| VEN/IRQ and NCI reset/init observed | PARTIAL; user log reaches NCI ready at `0x28`; electrical timing not observed |
| NFC-A read and held-tag behavior observed | PARTIAL; corrected read works per user, held-tag behavior PENDING |
| Explicit physical enrollment observed | PASS, user-reported |
| Unknown/enrolled tag alarm behavior observed | PENDING |
| Active reboot recovery with physical dismissal observed | PENDING |
| Reader disconnect/reconnect recovery observed | PENDING |
| Production enabled-alarm gate removal | BLOCKED on physical acceptance |

The user reports successful NFC-A reading and explicit enrollment on the corrected
development image. Update the remaining rows only with reproducible evidence,
distinguishing user-reported from agent-observed results.

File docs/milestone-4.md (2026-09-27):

# Milestone 4: durable settings and local setup

Firmware 0.4.0 adds the first complete persistence and local-configuration path.
It is compiled and host-tested but has not yet been flashed or exercised on the
physical clock for this milestone.

## Implemented

- A portable, fixed 195-byte settings record with schema, canonical validation,
  deterministic little-endian encoding and CRC32. It bounds eight alarms, eight
  tags, two tested timezones, device name, brightness, ambient mode and 1-5%
  maximum alarm volume.
- Separate NVS namespaces for settings and the alarm occurrence journal. The
  journal has its own magic, version, length and CRC. Writes compare the existing
  value first and commit only changed data.
- NVS initialization never auto-erases on full, corrupt or newer-format storage.
  Load/schema/checksum failures are visible faults and do not silently install or
  persist defaults.
- Settings load before alarm journal recovery. The alarm core receives one atomic
  configuration snapshot; accepted mutations are persisted before being applied.
- The audio ramp now captures the validated 1-5% configured maximum when ringing
  starts. Later configuration cannot lower an active alarm's captured volume.
- A three-second Button 2 hold while idle starts a 15-minute WPA2 SoftAP. Each
  start generates a new SSID and 12-character AP password from an OLED-friendly
  alphabet. The OLED initially shows a standard Wi-Fi join QR code plus the setup
  URL; Button 1 selects a text credential fallback. The QR uses medium error correction, a four-module quiet
  zone and Espressif's `qrcode` component pinned to 0.2.0. Credentials appear
  only on the OLED and are neither logged nor stored by the Wi-Fi driver.
- A self-contained local page at `http://192.168.4.1/` configures timezone,
  alarms, enrolled tag identifiers, display behavior, maximum volume, device name
  and manual UTC. It has no CDN or external assets.
- The web path bounds bodies, sockets, clients and request rate. Mutation
  responses acknowledge queue admission; durable acceptance is reported by clock
  status/logs. Access requires the WPA2 password; HTTP mutations retain a
  per-start CSRF token plus exact Host and Origin checks. Configuration requests
  are rejected while ringing. The AP is stopped
  if an alarm begins; alarm/audio tasks never wait for Wi-Fi.

## Security boundary

This increment uses HTTP only inside the temporary WPA2 SoftAP; it does not claim
transport confidentiality beyond that local radio link. CSRF and origin checks supplement WPA2 access control, but HTTPS with a locally
trusted certificate is not implemented. There is no STA/LAN listener, internet dependency, cloud service or
stored AP credential. Tag identifiers are still identifiers, not cryptographic
authentication.

Production deliberately rejects enabled alarm schedules until the physical
PN7160 dismissal path exists. If a production image finds enabled schedules left
by a development image, it suppresses them without erasing the NVS record. The
development profile remains the only profile suitable for alarm testing through
`nfc_sim`.

## Manual acceptance

Follow the README power-isolation rule, flash the development profile and verify
the `milestone 4 / 0.4.0` banner and `NVS initialization: READY`.

1. While idle, hold Button 2 for three seconds. Confirm the OLED shows a Wi-Fi QR, setup URL and remaining time. Press
   Button 1 and confirm the unique SSID and 12-character WPA2 password appear as text; press again for QR.
2. Scan the QR on a separate device and confirm it offers to join the clock AP.
   Browse to `http://192.168.4.1/`; confirm configuration opens directly,
   then save a tag before enabling an alarm.
3. Configure timezone, alarm, brightness/ambient behavior, maximum volume, device
   name and current UTC. Invalid/out-of-range requests must be rejected.
4. Reboot normally. Confirm `alarm_status` reports `NVS SETTINGS + JOURNAL` and the
   saved schedule/tag/timezone/display/volume behavior remains.
5. Start setup again and confirm the SSID and password changed. Wait for expiry or let
   an alarm start; the AP must stop without stopping or delaying the alarm.
6. While ringing, confirm setup cannot start and configuration requests are
   rejected. Dismiss with the development enrolled `nfc_sim` identifier.
7. Interrupt power after an alarm has durably started, reboot, and confirm it
   resumes. Dismiss it, reboot again, and confirm it does not resurrect.

## Remaining limitations

- The user reports that the current QR join, WPA2 connection and direct browser
  configuration page work on the physical device. This was not agent-observed.
- Device-side NVS failure injection, reboot recovery, AP expiry, configuration
  persistence and disconnection-during-alarm are not yet physically observed.
- There is no deliberate storage-repair/reset UI; corrupt/newer settings remain
  blocked and preserved for diagnosis rather than erased.
- No STA Wi-Fi, SNTP synchronization or HTTPS certificate workflow exists yet.
- Physical PN7160 NCI transport and RF tag enrollment/dismissal remain Milestone 5.

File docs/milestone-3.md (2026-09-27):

# Milestone 3: alarm core and simulated NFC

Firmware version 0.3.0. The portable alarm core is integrated through a dedicated
owner task and bounded queues. Both profiles compile against pinned ESP-IDF v6.1;
the host suite validates policy logic without ESP-IDF or hardware.

## Implemented behavior

- Up to eight weekday schedules and eight active overlaps in the portable core.
  Occurrences use stable alarm-ID/local-date keys and a UTC due time.
- UTC and `America/Los_Angeles` scheduling, including US DST rules before and
  after 2007. Spring-gap alarms are skipped and only the first fall-fold instance
  fires. Weekday masks use the local calendar.
- First valid-time acquisition does not ring retroactively. Later interruptions
  catch up at most five minutes; older occurrences increment a saturating missed
  counter without ringing. Backward clock changes do not replay occurrences.
- The journal contract persists activation before requesting audio and persists
  authorized dismissal before requesting silence. Failed activation writes do
  not start sound; failed dismissal writes leave the alarm active. Cursor-only
  progress checkpoints every five minutes, while state changes commit immediately.
- Active occurrences and their frozen enrolled-tag snapshot can be restored by a
  durable journal. The host suite covers recovery, corrupt loads and injected
  save failures. Milestone 3's device adapter is intentionally RAM-only; NVS is
  Milestone 4 work.
- Corrupt or failed journal loads block mutation/evaluation writes, preventing a
  fault from being silently treated as empty or overwritten.
- One audio stream serves overlapping occurrences. It ramps a 440 Hz tone from
  1% to the user-verified 5% digital peak over 30 seconds, then holds 5% until an
  authorized dismissal.
- The development profile exposes RAM-only setup, immediate trigger and `nfc_sim`.
  Simulated tags enter the same `handle_tag` authorization method reserved for a
  future physical reader. Unknown tags and ordinary controls never dismiss.
- The production console contains no simulator/setup/trigger commands, and the
  checked simulator markers are absent from its ELF. With no durable configuration
  yet, production alarm mutation remains disabled.

## Development console

| Command | Behavior |
| --- | --- |
| `alarm_status` | Report owner state, active/missed counts, zone and RAM-only persistence |
| `tag_enroll HEX_UID` | Development-only RAM enrollment; 1-10 UID bytes |
| `alarm_zone UTC` | Select UTC for future evaluation |
| `alarm_zone America/Los_Angeles` | Select tested Pacific rules for future evaluation |
| `alarm_set HH:MM SMTWTFS` | Development-only alarm ID 1; seven `0`/`1` weekday bits |
| `alarm_trigger` | Development-only immediate occurrence; requires valid time and enrolled tag |
| `nfc_sim HEX_UID` | Development-only tag event through the normal authorization path |

`tag_enroll`, `alarm_zone`, `alarm_set`, `alarm_trigger` and `nfc_sim` require both
`CLOCK_DEVELOPMENT_BUILD` and `CLOCK_SIMULATED_NFC` through the Kconfig dependency
and compile-time check. They are absent from the production console and artifact.
The OLED displays `DEV SIM NFC - RAM ONLY` whenever that profile is running.

While ringing, time setting, audio tests, schedule/timezone changes, enrollment
and another trigger are rejected. Buttons and encoder operations remain available
for diagnostics/brightness but are not dismissal events. Tag identifiers are not
cryptographic authentication, and this device is not tamper-proof.

## Physical NFC boundary

The user reports the PN7160 board is connected. Milestone 3 does not configure
GPIO15 IRQ, GPIO16 VEN, register an I2C transport, or send NCI packets. The scan
labels ACKs at 0x28-0x2B as possible PN7160 presence only. A missing ACK does not
yet diagnose the board because VEN sequencing is not implemented. Before the
physical integration milestone, confirm the I2C board variant, 3.3 V selection,
ADDR strap state, and expected VEN/IRQ behavior.

## Remaining limitations

- Reset loses the development alarm, tags, timezone and RAM journal. Do not use
  this profile as an alarm clock. Durable schema-versioned settings and journal
  integration arrive in Milestone 4.
- No web UI, Wi-Fi setup, physical PN7160 reader, enrollment mode, or production
  configuration path exists yet.
- The user reports the device alarm sounded and was dismissed through the enrolled
  simulated-tag path. This was not agent-observed and does not validate physical NFC;
  the remaining bypass, unknown-tag and schedule cases have not been reported.
- Existing RTC retention, calibrated battery accuracy and peripheral fault tests
  from Milestone 2 remain open.

Use the root README for the mandatory boost/USB power isolation rule, exact build
and flash commands, and the manual simulator acceptance sequence.

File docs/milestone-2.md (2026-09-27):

# Milestone 2: peripheral bring-up

Firmware version 0.2.0. Production/development builds compile against the pinned
ESP-IDF v6.1 without Arduino or new component dependencies. The user verified
milestone 1 on-device. For milestone 2, the user reports the OLED, encoder/light
sensing and 5% audio test work; these are not agent-observed tests. RTC retention,
battery accuracy and the remaining fault-recovery checks are still unverified.

## What is implemented

| Area | Behavior |
| --- | --- |
| I2C | GPIO8/9 at 100 kHz, external module pull-ups; address discovery and serialized transfers |
| Display | SH1107 reset on GPIO10, 64x128 native buffer rotated to 128x64 landscape; clock and status pages |
| RTC | Read/validate PCF8523, initialize system UTC from valid RTC, explicit manual setting, enable battery switchover when setting |
| Controls | GPIO11/12 and seesaw GPIO24 switch with 30 ms debounce; encoder position polling and rollover handling |
| Audio | Dedicated task; explicit 440 Hz test, two seconds, 1% digital peak and 100 ms envelope, stereo mono mix |
| Battery | ADC1 channel 0 / GPIO1, 12 dB attenuation, 16-sample average, eFuse calibration if available, nominal divider factor 2 |
| Light | BH1750 continuous high-resolution mode; lux reading and optional coarse ambient dimming |
| Diagnostics | Local serial commands, time/peripheral status, memory and heartbeat logs; no radio or web service |

Exact build, flash, monitor and manual test instructions are in the root README.
The existing `build/m1` and `build/m1-dev` names are intentionally retained; they
build the current source, not a frozen milestone 1 image. Use commit `03fb405` in
a separate checkout if a milestone 1 rebuild is needed. No settings/NVS partition
layout change is required for milestone 2.

## Serial commands and physical controls

| Input | Result |
| --- | --- |
| `help` | Command list |
| `clock_status` | UTC validity/source, RTC/OLED/encoder/audio status, ADC, battery mV, lux |
| `i2c_scan` | Probe non-reserved 7-bit addresses; stop early on bus timeout/error |
| `clock_set YYYY-MM-DDTHH:MM:SSZ` | Validate and set actual UTC; attempt RTC write and report failures |
| `audio_test [1\|5]` | Start bounded tone at 1% (default) or 5% digital peak if ready and idle |
| `brightness 1` through `brightness 255` | OLED contrast; no persistence yet |
| `ambient on` / `ambient off` | Enable/disable light-based contrast ceiling; no persistence yet |
| Encoder rotation | Adjust contrast, clockwise positive for the preassembled 5880 |
| Encoder push / button 1 | Alternate OLED clock/status page |
| Button 2 | Log status only |

No physical input starts sound automatically. Boot is silent. In development,
serial and OLED identify the development build; simulated NFC events are still
pending milestone 3. This console is a locally attached diagnostic interface,
not an authenticated network API. Before integrating the alarm state machine,
route diagnostic intents through it and enforce the ringing restrictions on
time changes, audio tests and any future reset/enrollment operations.

## Fault handling and boundaries

- RTC invalid BCD/calendar, oscillator-stop or STOP/12-hour flags prevent using
  its time. Disabled/invalid battery backup modes request manual setting.
  Battery-low or disabled-monitor status is visible. Manual setting selects
  24-hour mode and standard battery switchover, retaining oscillator capacitance.
- A successful system time set remains usable in RAM if RTC writes fail. A
  partial RTC write can leave it stopped: report the fault, then retry
  `clock_set` after fixing the connection. No fabricated build-time fallback.
  Subsequent RTC reads check validity; battery retention and accuracy still
  require the power-cycle/multimeter checks in the README.
- System time is initialized once from valid RTC or explicitly set. A later
  RTC communication failure does not erase the running system time; status shows
  the fault while the MCU clock provides holdover. Periodic network sync and
  timezone/DST handling are not implemented in this milestone.
- Every I2C transfer has a 20 ms driver timeout and a 30 ms mutex acquisition
  limit. Failed devices retry after five seconds. Device transfers and command
  handling share one peripheral task, so faults may slow its UI/controls polling.
  The audio task is independent. The future alarm task must also be independent.
- OLED updates send one 64-byte page per task iteration rather than monopolizing
  the bus for a complete frame. Initialization has bounded reset/startup delays.
  A shared bus short can make all I2C devices unavailable; firmware cannot isolate
  the electrical fault. Direct buttons, UART and I2S can still operate.
- Audio has no automatic amplifier/speaker presence detection. `READY/UNVERIFIED`
  means the ESP32 I2S driver initialized. Requests while busy are rejected. DMA
  writes have a 100 ms timeout; silence is flushed before clocks stop. A driver
  failure disables further tests until reboot. This is not an amplifier SD control.
  The optional `audio_test 5` diagnostic raises digital amplitude fivefold without
  changing the duration, envelope, wiring or hardware gain. Invalid levels are
  rejected by the console and driver. Host tests verify the generated PCM, not
  DMA transfers or electrical signals. The configured Philips I2S format uses
  16-bit stereo slots at 16 kHz: nominal LRC 16 kHz, BCLK 512 kHz. This format is
  supported by the [MAX98357A datasheet](https://www.analog.com/media/en/technical-documentation/data-sheets/max98357a-max98357b.pdf).
- ADC calibration is not a calibrated battery gauge. `-1` denotes an unavailable
  measurement; raw counts remain available when eFuse calibration is unavailable.
  No battery charge limiting, low-battery shutdown or runtime estimate is provided.
- Ambient mode uses contrast ceilings 8/32/79/160 at lux bands below 5/50/200/above,
  bounded by manual brightness. Missing light data restores manual contrast.
  This is a bring-up policy; smoothing/hysteresis can follow physical testing.

## Protocol references checked

The native IDF APIs were checked against the installed v6.1 headers and compiled.
Device register behavior was checked against manufacturer references:

- [Adafruit SH1107 source](https://github.com/adafruit/Adafruit_SH110x/blob/master/Adafruit_SH1107.cpp)
  and [SH110X page transfers](https://github.com/adafruit/Adafruit_SH110x/blob/master/Adafruit_SH110X.cpp).
  Adapted initialization/page addressing is covered by `THIRD_PARTY_NOTICES.md`.
- [NXP PCF8523 datasheet](https://www.nxp.com/docs/en/data-sheet/PCF8523.pdf),
  register map, oscillator validity and battery-management modes; compared with
  [Adafruit RTClib](https://github.com/adafruit/RTClib/blob/master/src/RTC_PCF8523.cpp).
- [Adafruit encoder guide](https://learn.adafruit.com/adafruit-i2c-qt-rotary-encoder/arduino)
  confirms firmware product ID 4991, switch on seesaw GPIO24 and reversed direction
  on preassembled product 5880. Native register reads use STOP, a processing delay
  and a separate read, as in the [seesaw driver](https://github.com/adafruit/Adafruit_Seesaw).
- [Adafruit BH1750 implementation](https://github.com/adafruit/Adafruit_CircuitPython_BH1750/blob/main/adafruit_bh1750.py)
  for measurement mode, conversion delay and default scaling.

Reference drivers are not build dependencies; no online downloads are needed to
build these modules. No hardware files or pin assignments were changed.

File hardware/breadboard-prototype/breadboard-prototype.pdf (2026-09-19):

1 | 2 | 3 | 4 | 5 | 6 | 7 | 8
1 | 2 | 3 | 4 | 5 | 6 | 7 | 8

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
Size: A3 | Rev: | F Date:
KiCad E.D.A. 10.0.6 | Id: 1/1

## Title:

## File: NFC_Alarm_Prototype.kicad_sch

## Sheet: /

C1

220uF / 25V

3VGND

RST SCL SDA | U5

# 4650 / SH1107 GND

SCL SDA

VIN

U7

4681 / BH1750

1
2

LS1
4 ohm / 3W

GND

INT SCL SDA

VIN

U8

5880 / seesaw

SW1 B3F-1020

BT1

1S LiPo +BATT | R1 100k R2 100k

BATT_/_LIPO

GND USB-C_/_VBUS | LOAD_OUT U2
4755 / BQ24074 | C2
100nF | SW2 B3F-1020 GND

VCC

GND | EN
IN | OUT_/_5.2V U3

4654 / TPS61023

PWR_FLAG

GND

SCL SDA

VCC | SQW

U6

5189 / PCF8523 GND

3V3_[7]

GND_[8] | GND_[9]
SDA_[11] SCL_[12] | INT_/_IRQ_[15]

PWM_/_VEN_[16] U9 MIKROE-6453 / PN7160 BCLK

DIN

GAIN

GND

LRC

SPK_-

SPK_+

SD

VIN

U4

3006 / MAX98357A | GND +BATT

GND

GND

IO1_/_ADC

3V3

IO5_/_BCLK

5V

IO6_/_LRCLK

IO7_/_DIN

IO8_/_SDA

IO9_/_SCL

IO10

IO11

IO12

IO15 | IO16 GND | U1

ESP32-S3 N32R16V

PWR_FLAG | PWR_FLAG
VBUS | +BATT | +3V3

I2C_SDA

BAT_ADC | NFC_IRQ
GND | GND
I2C_SDA SPK_MINUS | NFC_VEN

I2C_SCL

# NFC_IRQ +3V3

VCC

I2S_DIN

I2S_LRC

I2S_BCLK

SPK_PLUS

VCC

GND

VCC

GND | +5V
| VCC

VCC

BUTTON_2

GND +BATT VBUS

BUTTON_1 | GND

I2C_SCL

I2C_SCL

# I2C_SDAGND

GND

I2S_DIN

GND

# I2C_SDA +3V3 +3V3 GND

I2C_SCL

I2C_SDA OLED_RST BUTTON_1

I2S_LRC NFC_VEN

BAT_ADC

I2S_BCLK

I2C_SCL

I2C_SDA | OLED_RST
I2C_SCL GND +5V BUTTON_2 +3V3 GND | +3V3 BH1750, default I2C 0x23. Power from 3.3 V. ROTARY ENCODER + PUSH
3.3 V GPIO. Configure octal flash and PSRAM. Web configuration over Wi-Fi; MCU stays awake. | Seesaw, default I2C 0x36. Poll rotation and push over I2C.

INT unused. Module handles encoder decoding.

# BUTTONS

# Enable internal pull-ups; pressed = LOW. AMBIENT LIGHT

SH1107, I2C 0x3C. Pulse RST at startup. Use Adafruit SH110X driver. OLED buttons unused. WI-FI CONTROLLER

GAIN to VIN = 6 dB. SD open uses onboard mono mix. Place C1 close to amplifier VIN/GND; observe polarity.

Keep speaker pair short; neither speaker wire goes to GND. External USB / battery / ground source declarations: All grounds common. I2C uses 3.3 V; begin at 100 kHz with short wires. Breakout boards include pull-ups and decoupling; extra bus pull-ups are not fitted. Test combined 3.3 V load during Wi-Fi + NFC activity before relying on battery mode. Functional breadboard wiring only: no PCB layout or fabrication footprints. U9 is the proposed PN7160 module; confirm this model before buying/wiring.

# ASSEMBLY NOTES

U2: built-in USB-C input, 5 V supply. Set charge jumper to 500 mA for BT1. VCC = LOAD OUT, approximately 3-4.4 V. | Battery divider: read BAT, not LOAD OUT. ADC maximum 2.1 V; configure attenuation

and calibrate. C2 filters the ADC input. U9: MIKROE-6453 NFC 7 Click I2C / PN7160. Set VCC SEL to 3.3 V and interface straps to I2C. VEN is mikroBUS PWM; IRQ is INT. RST is ClickID, unused. Keep antenna clear of metal, speaker, and power wiring.

# REAL-TIME CLOCK

PCF8523, I2C 0x68. Insert CR1220 in onboard holder. SQW unused: alarms handled by running firmware. NFC-dismiss alarm clock | Breadboard prototype

Revision A - Module terminal names follow board silkscreen; onboard circuits and unused headers omitted. USB / BATTERY / POWER

# I2S AUDIO

BT1: protected 1S LiPo, 4.2 V full. Check JST polarity. U3: +5V net is nominally 5.2 V. EN tied to IN. Disconnect U3 OUT from U1 5V before programming by USB. | DISPLAY

# NFC READER

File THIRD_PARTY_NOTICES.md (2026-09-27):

# Third-party notices

The SH1107 initialization and page addressing in `main/drivers/display.cpp`
are adapted from Adafruit_SH110x. Upstream reference:
https://github.com/adafruit/Adafruit_SH110x (retrieved 2026-09-19).
The rest of the firmware uses ESP-IDF and original device-register drivers.
ESP-IDF retains its own licenses in the pinned SDK distribution.

```text
Software License Agreement (BSD License)

Copyright (c) 2012, Adafruit Industries
All rights reserved.

Redistribution and use in source and binary forms, with or without
modification, are permitted provided that the following conditions are met:
1. Redistributions of source code must retain the above copyright
notice, this list of conditions and the following disclaimer.
2. Redistributions in binary form must reproduce the above copyright
notice, this list of conditions and the following disclaimer in the
documentation and/or other materials provided with the distribution.
3. Neither the name of the copyright holders nor the
names of its contributors may be used to endorse or promote products
derived from this software without specific prior written permission.

THIS SOFTWARE IS PROVIDED BY THE COPYRIGHT HOLDERS ''AS IS'' AND ANY
EXPRESS OR IMPLIED WARRANTIES, INCLUDING, BUT NOT LIMITED TO, THE IMPLIED
WARRANTIES OF MERCHANTABILITY AND FITNESS FOR A PARTICULAR PURPOSE ARE
DISCLAIMED. IN NO EVENT SHALL THE COPYRIGHT HOLDER BE LIABLE FOR ANY
DIRECT, INDIRECT, INCIDENTAL, SPECIAL, EXEMPLARY, OR CONSEQUENTIAL DAMAGES
(INCLUDING, BUT NOT LIMITED TO, PROCUREMENT OF SUBSTITUTE GOODS OR SERVICES;
LOSS OF USE, DATA, OR PROFITS; OR BUSINESS INTERRUPTION) HOWEVER CAUSED AND
ON ANY THEORY OF LIABILITY, WHETHER IN CONTRACT, STRICT LIABILITY, OR TORT
(INCLUDING NEGLIGENCE OR OTHERWISE) ARISING IN ANY WAY OUT OF THE USE OF THIS
SOFTWARE, EVEN IF ADVISED OF THE POSSIBILITY OF SUCH DAMAGE.
```

## QR code generator

`espressif/qrcode` version 0.2.0 is resolved from the ESP Component Registry and
distributed under Apache-2.0. It incorporates Project Nayuki's QR Code generator;
the downloaded component retains Espressif's Apache-2.0 license and the upstream
source retains the following MIT notice.

```text
MIT License

Copyright (c) Project Nayuki

Permission is hereby granted, free of charge, to any person obtaining a copy
of this software and associated documentation files (the "Software"), to deal
in the Software without restriction, including without limitation the rights
to use, copy, modify, merge, publish, distribute, sublicense, and/or sell
copies of the Software, and to permit persons to whom the Software is
furnished to do so, subject to the following conditions:

The above copyright notice and this permission notice shall be included in
all copies or substantial portions of the Software.

THE SOFTWARE IS PROVIDED "AS IS", WITHOUT WARRANTY OF ANY KIND, EXPRESS OR
IMPLIED, INCLUDING BUT NOT LIMITED TO THE WARRANTIES OF MERCHANTABILITY,
FITNESS FOR A PARTICULAR PURPOSE AND NONINFRINGEMENT. IN NO EVENT SHALL THE
AUTHORS OR COPYRIGHT HOLDERS BE LIABLE FOR ANY CLAIM, DAMAGES OR OTHER
LIABILITY, WHETHER IN AN ACTION OF CONTRACT, TORT OR OTHERWISE, ARISING FROM,
OUT OF OR IN CONNECTION WITH THE SOFTWARE OR THE USE OR OTHER DEALINGS IN THE
SOFTWARE.

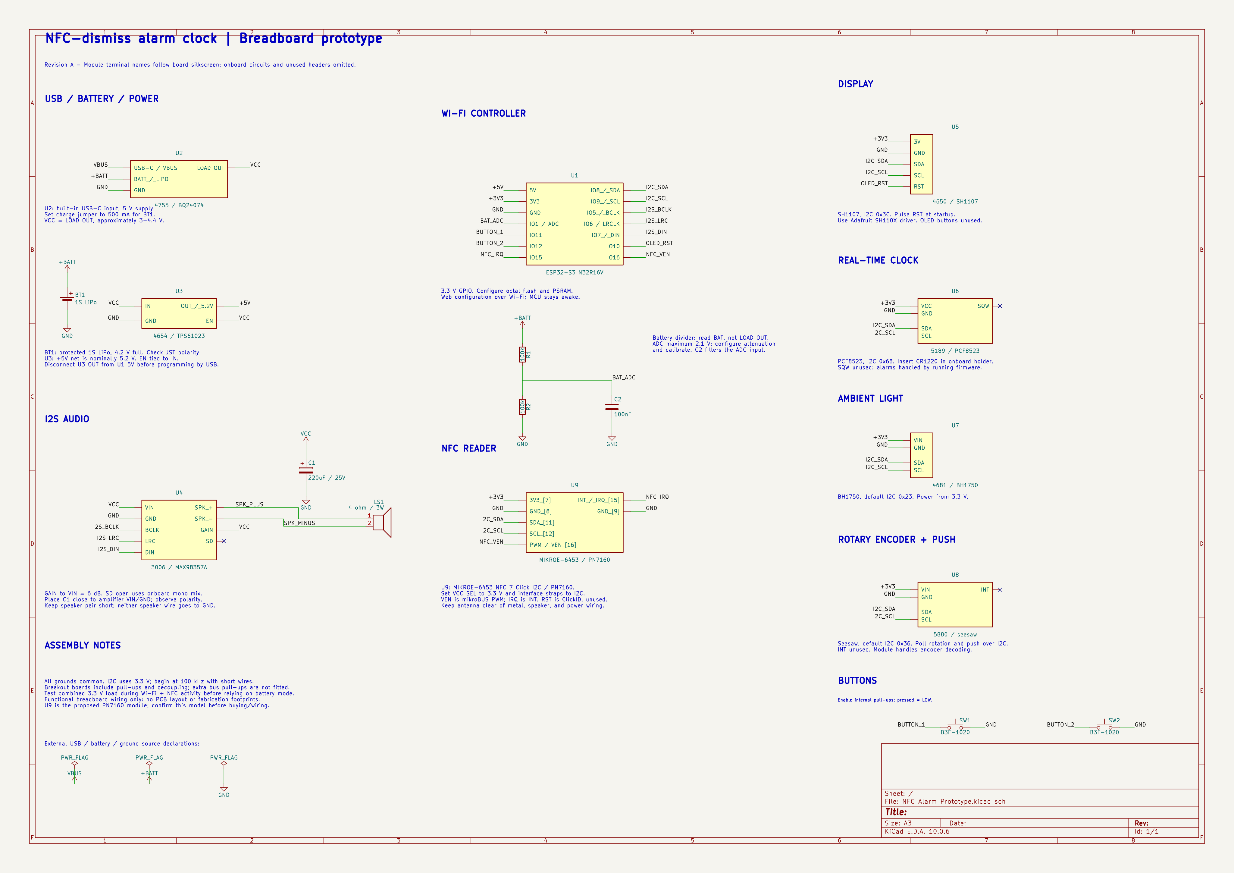
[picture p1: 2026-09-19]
hardware/breadboard-prototype/breadboard-prototype.png

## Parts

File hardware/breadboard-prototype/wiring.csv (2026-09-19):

Module/reference | Terminal | Signal / power rail
U1 | 5V | +5V
U1 | 3V3 | +3V3
U1 | GND | GND
U1 | 1 | BAT_ADC
U1 | 11 | BUTTON_1
U1 | 12 | BUTTON_2
U1 | 15 | NFC_IRQ
U1 | 8 | I2C_SDA
U1 | 9 | I2C_SCL
U1 | 5 | I2S_BCLK
U1 | 6 | I2S_LRC
U1 | 7 | I2S_DIN
U1 | 10 | OLED_RST
U1 | 16 | NFC_VEN
U2 | VBUS | VBUS
U2 | BAT | +BATT
U2 | GND | GND
U2 | OUT | VCC
U3 | IN | VCC
U3 | GND | GND
U3 | OUT | +5V
U3 | EN | VCC
U4 | VIN | VCC
U4 | GND | GND
U4 | BCLK | I2S_BCLK
U4 | LRC | I2S_LRC
U4 | DIN | I2S_DIN
U4 | PLUS | SPK_PLUS
U4 | MINUS | SPK_MINUS
U4 | GAIN | VCC
U4 | SD | Leave open
U5 | 3V | +3V3
U5 | GND | GND
U5 | SDA | I2C_SDA
U5 | SCL | I2C_SCL
U5 | RST | OLED_RST
U6 | VCC | +3V3
U6 | GND | GND
U6 | SDA | I2C_SDA
U6 | SCL | I2C_SCL
U6 | SQW | Leave open
U7 | VIN | +3V3
U7 | GND | GND
U7 | SDA | I2C_SDA
U7 | SCL | I2C_SCL
U8 | VIN | +3V3
U8 | GND | GND
U8 | SDA | I2C_SDA
U8 | SCL | I2C_SCL
U8 | INT | Leave open
U9 | 7 | +3V3
U9 | 8 | GND
U9 | 11 | I2C_SDA
U9 | 12 | I2C_SCL
U9 | 16 | NFC_VEN
U9 | 15 | NFC_IRQ
U9 | 9 | GND
BT1 | 1 | +BATT
BT1 | 2 | GND
C1 | 1 | VCC
C1 | 2 | GND
LS1 | 1 | SPK_PLUS
LS1 | 2 | SPK_MINUS
R1 | 1 | +BATT
R1 | 2 | BAT_ADC
R2 | 1 | BAT_ADC
R2 | 2 | GND
C2 | 1 | BAT_ADC
C2 | 2 | GND
SW1 | 1 | BUTTON_1
SW1 | 2 | GND
SW2 | 1 | BUTTON_2
SW2 | 2 | GND

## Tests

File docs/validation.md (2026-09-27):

# Validation record

Milestone 1, 2026-09-19, ESP-IDF v6.1 commit
`fff9895c82d744c7237be8847347bdd1b07c6643`, Xtensa toolchain supplied by EIM.

| Check | Result |
| --- | --- |
| Production clean isolated build | PASS, application 181600 bytes |
| Development clean isolated build | PASS, application 181696 bytes |
| IDF bootloader and partition size checks | PASS, factory partition 4 MiB |
| Generated ESP32-S3, 32 MB OPI/DTR 80 MHz, octal PSRAM 80 MHz configuration | PASS both profiles |
| Development/simulation settings | OFF production; ON development |
| Production checker given development build | Correctly rejected |
| Wiring CSV vs supplied exported netlist | PASS, 73 terminals agree |
| Supplied hardware file hashes | Unchanged from inspection through final check |
| `git diff --check` | PASS |

Builds emit upstream IDF CMake component dependency/include visibility warnings;
neither application compilation nor linking failed. Initial CMake version-check
failure was fixed before the successful builds. Build logs are preserved in
`build/m1/build-verification.log` and `build/m1-dev/build-verification.log`.

Reproduce configuration/artifact checks after building with the README commands:

```bash
python3 tools/check_build.py build/m1
python3 tools/check_build.py build/m1-dev --development
```

Application SHA-256 values (exact current build artifacts, not a promise of
byte-identical binaries across environment/path changes):

```text
production  2a92c49a673a7d1f9fa18c1e5707335a561b94fa0190e794442c101a93a15846
development 7daf101cfbae252ab4a4ac689be184ad2e86bd6c0886a83352e0129bd284687e
```

Milestone 1 hardware execution: the **user subsequently reported that it works on
the device** after commit `03fb405`. No agent-observed serial log or item-by-item
acceptance result was supplied. This does not verify milestone 2 peripherals.

## Milestone 2, firmware 0.2.0

Implemented peripheral drivers and serial integration without changing the SDK,
partition layout, wiring or hardware files. Build directories retain their
existing names for VS Code compatibility.

| Check | Result |
| --- | --- |
| First driver increment | Compiled I2C, RTC, sensing, controls and portable helpers |
| Integrated production build (`build/m1`) | PASS, application 317488 bytes |
| Integrated development build (`build/m1-dev`) | PASS, application 317600 bytes |
| IDF bootloader/application partition checks | PASS, application fits 4 MiB partition |
| Memory configuration and profile/artifact checker | PASS both profiles |
| Production checker given development artifacts | Correctly rejected |
| Host CTest suite | PASS, 1 executable containing calendar/control cases |
| Calendar coverage | Every valid date in 2000–2099 round-trips through RTC BCD |
| UTC validation | Known epoch values; reject invalid leap dates, days, ranges, syntax and trailing data |
| RTC validity | Reject OS, STOP, 12-hour format, invalid BCD and impossible dates |
| Controls | Bounce rejection, one event per stable transition and modulo encoder rollover |
| Whitespace and hardware diff checks | PASS; no hardware changes |

The first integrated compile found a missing C++ iterator include and incomplete
console command initializers; both were fixed and the final builds passed with
no application compiler warnings. IDF can still emit its upstream CMake component
visibility warnings on reconfiguration. Logs are retained locally as
`build/m1/milestone-2-build.log` and `build/m1-dev/milestone-2-build.log`.

Initial milestone 2 application SHA-256 values (before the OLED retry fix below):

```text
production  3de171879aa6c0906f972ca82a95b2e810e6b1c452f0572b29b7e2d52b4866db
development 5db2e3dec8061dd4f7ef880cc7ada68f91ca9157d9d5212d3e865f77d8d63e43
```

**Milestone 2 hardware execution: not performed.** No firmware flash, serial
monitor, physical peripheral/audio test or battery-runtime measurement was
performed by the agent. The portable tests do not mock or validate IDF drivers.
RTC retention, display layout, I2C fault recovery, audio amplitude and calibrated
voltage accuracy all require the README's on-device tests. No alarm scheduler
tests exist yet because scheduling is not implemented; those are a required
milestone 3 gate, and persistent settings validation tests are a milestone 4 gate.

### User bring-up report and OLED retry correction (2026-09-21)

The user reports milestone 2 flashed successfully, with no OLED image or speaker
sound; other features seemed to work. Supplied serial output shows ACKs at 0x23,
0x36 and 0x68, a verified seesaw product 4991 / hardware ID 0x55, RTC invalid time,
OLED missing/I/O error, and audio driver initialized but physically unverified.
Battery readout was 880 mV; this is not validated battery voltage. The first lux
sample was unavailable while measurement startup was pending. No audio-test
start/completion/error log or later light reading was supplied.

Inspected the installed IDF v6.1 `gpio.c`: configuring an already-reserved output
prints `conflict found for GPIO`. The OLED retry path was reconfiguring its own
GPIO10 every five seconds. Changed it to configure that pin once, retaining the
reset pulse on subsequent device-init attempts. Added an explicit probe error.
This addresses the misleading warning; it does not establish the reason for the
missing OLED ACK or verify physical display/audio output. No pin assignments or
hardware files were changed by this correction.

Correction validation: production and development builds and their generated
configuration/artifact checks pass. Logs: `build/m1/oled-retry-fix-build.log` and
`build/m1-dev/oled-retry-fix-build.log`. Not flashed by the agent. On-device check:
with OLED still absent, wait through two five-second retries; expect explicit
probe failures without repeated GPIO10 configuration-conflict warnings.

### Audio troubleshooting and optional 5% test (2026-09-26)

User reports the OLED now works. Their log shows a completed 1% audio test without
driver errors, OLED/encoder OK and lux 104.2. RTC remains invalid and battery ADC
reports 94 mV; neither RTC time nor battery measurement is thereby validated.
User measured amplifier VIN around 4.3 V, SD around 416 mV, speaker resistance
4 ohms and good wiring continuity, but still hears no sound. These observations
do not establish I2S signal integrity or acoustic output.

Added `audio_test 5`; no argument remains 1%. Only 1% and 5% levels are accepted,
with unchanged two-second duration, 100 ms fades, both channels identical, and
busy rejection. No pin assignment, amplifier gain, SD or hardware changes.
The configured I2S mode matches the MAX98357A-supported 16-bit stereo Philips
format; an added log gives expected pin/clock settings, explicitly not measured.

Host tests pass for command-level validation, nonzero PCM, 440 Hz frequency,
peak limits, endpoint silence, fades and fivefold amplitude. Existing calendar/
control tests also pass (2/2 CTest executables). This does not verify the DMA
output or the amplifier. No agent flashing or physical audio test performed.

Production and development firmware builds pass, as do both generated
configuration/artifact checks. Build logs: `build/m1/audio-level-build.log` and
`build/m1-dev/audio-level-build.log`.

Manual check: use the README's build/flash commands and power procedure
(disconnect U3 OUT from U1 5V before programming USB). Keep amplifier VIN on
charger LOAD OUT with common ground. Run `audio_test 5` once; expect the 5% start
message, a two-second tone and completion. If silent, retain the log for further
I2S/hardware diagnosis; do not infer a failed amplifier from software success.

### User audio confirmation (2026-09-27)

The user reports that audio works: the original 1% test was too quiet to hear,
while the 5% diagnostic tone is audible. This is user-reported physical validation,
not an agent-observed test or a calibrated acoustic measurement. It confirms the
prototype can produce the bounded test tone at 5% with the current wiring and
firmware; it does not validate RTC retention, battery-voltage accuracy, peripheral
fault recovery or alarm behavior, which is not implemented yet.

Final pre-commit validation rebuilt both pinned profiles and reran all checks:

| Check | Result |
| --- | --- |
| Production build/checker | PASS, 318128-byte application |
| Development build/checker | PASS, 318256-byte application |
| Host CTest suite | PASS, 2/2 executables |
| `git diff --check` | PASS |

```text
production  7b490052962865de0330ecfb19ae465c12f31f212641cf556b7e2341ff16fd4c
development 7deead73616cf244f991046288f9b7b8c2f1c80b5ec04aa45ee0002a164e41b6
```

## Milestone 3, firmware 0.3.0

Implemented and host-tested the portable alarm state machine, calendar scheduling,
curated timezone conversion, journal contract, tag authorization and alarm audio
ramp. Integrated them with a dedicated FreeRTOS owner task and bounded event queue.

| Check | Result |
| --- | --- |
| UTC/local scheduling and weekday masks | PASS |
| Pacific spring gap / fall fold | PASS; skip gap, first fold only |
| First time, forward catch-up and backward changes | PASS; no first-time/backward replay, five-minute window |
| Overlapping occurrences | PASS; one start action and one tag dismisses active set |
| Known/unknown tags and frozen snapshot recovery | PASS |
| Ringing bypass attempts | PASS; schedule, zone and enrollment mutations rejected |
| Activation/dismissal save failures | PASS; no pre-journal sound, no pre-journal silence |
| Corrupt journal and active recovery | PASS; visible fault / restored start action |
| Alarm audio ramp | PASS; nonzero, monotonic 1%-5%, bounded and repeating |
| Host CTest suite | PASS, 3/3 executables |
| Production firmware build/checker | PASS, 327792-byte application |
| Development firmware build/checker | PASS, 329152-byte application |
| Simulator artifact markers | Absent production; present development |
| `git diff --check` | PASS |

The production build compiles the portable core but exposes no mutation, trigger
or simulated-tag console commands. The build checker verifies `nfc_sim` and the development
OLED marker are absent from the production ELF and present in development. The
device development adapter is RAM-only; host recovery tests exercise the abstract
durable-journal contract, not NVS. NVS implementation and migration/failure tests
remain Milestone 4.

Final application SHA-256 values:

```text
production  19ac24480cc33ef428ea781273ca2f1eaea528118cf7b52a6ced18be7bce0eea
development e7e5f4879900fb6bc7a0420c2ac811d64bd7df64e4535689f8887154775a8744
```

No Milestone 3 firmware was flashed or physically tested by the agent. The user
reports that the development alarm sounded and was dismissed through its enrolled
simulated-tag path on the device. This validates the principal device integration
path but was not agent-observed; the exact remaining manual cases were not reported.
The PN7160 board is connected, but no strap/address/IRQ/VEN/NCI result has been
supplied. GPIO15/16 remain untouched and physical NFC dismissal
is not implemented. Follow `docs/milestone-3.md` and the README for manual checks.

## Milestone 4 increment, firmware 0.4.0

Implemented and host-tested deterministic settings validation/serialization,
atomic configuration replacement, bounded configurable alarm volume, separate
checksum-protected NVS settings/journal records, and a time-limited WPA2-protected
SoftAP web UI.

| Check | Result |
| --- | --- |
| Settings bounds, canonical form and duplicate IDs/tags | PASS |
| Settings stable little-endian encode/decode and CRC corruption | PASS |
| Unsupported settings schema preserved/rejected | PASS |
| Enabled alarm without enrolled tag | Rejected |
| Atomic pre-recovery configuration and ringing mutation rejection | PASS |
| Alarm volume 1-5% bounds and ramp | PASS |
| Host CTest suite | PASS, 4/4 executables |
| Production firmware build/checker | PASS, 0xf3970-byte application |
| Development firmware build/checker | PASS, 0xf3da0-byte application |
| NVS/setup artifact markers | Present in both profiles |
| Simulator artifact markers | Absent production; present development |
| Production active-journal safety marker | Present production; absent development |

Final application SHA-256 values:

```text
production  e46048b752bb6a2636823d3fe8ef55e873a98492a90090c27b36549e64a9a505
development d4aeafb518780fef8f40a892de7e3876590ade711afec2f47de45d3522d224af
```

The NVS implementation uses explicit encodings rather than raw C++ object layout,
compares before writes, commits changed records, and never automatically erases a
full, corrupt or newer-format partition. Production rejects new enabled schedules
and suppresses enabled development schedules loaded from NVS because physical NFC
dismissal does not exist yet.

The user reports that the current Milestone 4 QR join, WPA2 connection and direct
browser configuration page work on the physical device. This was not agent-observed. AP expiry,
configuration persistence, alarm-time disconnection, physical reboot persistence
and alarm recovery remain manual checks. HTTP is confined to
the temporary WPA2 AP with CSRF/Host/Origin protections; HTTPS and STA/LAN
access are not implemented. Web mutation responses acknowledge bounded queue
admission; confirm durable acceptance in clock status/logs.

## Milestone 5 development increment, firmware 0.5.0

Milestone 5 begins staged physical PN7160 integration. The implementation is
present, the five-executable host suite passes, and both firmware profiles compile
and pass their artifact checks. The user reports that the corrected development
image identifies the controller at `0x28`, reads an NFC-A identifier and persists
it through the explicit physical enrollment window. The exact board variant,
3.3 V selection, straps and pin-level IRQ/VEN timing remain unverified.

| Check | Result |
| --- | --- |
| Portable NCI framing/discovery tests | PASS; host CTest suite 5/5 |
| Production firmware build/checker | PASS; app `0xf5cf0`, SHA-256 `9b528526381ddd293d13c8451557de12d28421455f52aa41706dc1ccf77c1a20` |
| Development firmware build/checker | PASS; app `0xf6080`, SHA-256 `e2a972449dceaf8445eca080e9aa7c5d2078effeb92fa8704acd32f20806f0b9` |
| `git diff --check` | PASS |
| I2C variant and 3.3 V selection inspected | PENDING, physical |
| Address straps and NCI-identified 0x28-0x2B address | PARTIAL; user log identifies NCI at `0x28`, straps not inspected |
| VEN boot, active-high IRQ, CORE_RESET/CORE_INIT | PARTIAL; user log reaches NCI-ready state, no pin-level observation |
| NFC-A identifier and held-tag de-duplication | PARTIAL; user reports corrected identifier read works; held-tag behavior PENDING |
| Idle/time-limited physical enrollment | PASS, user-reported on corrected development image |
| Unknown/enrolled tag dismissal path | PENDING, physical |
| Active reboot recovery with physical tag | PENDING, physical |
| Disconnected/reconnected reader recovery | PENDING, physical |
| Production enabled-alarm gate | RETAINED pending all physical acceptance |

The implementation policy is that IRQ waits occur without holding the shared I2C
bus, all transactions and command waits are finite, and a reader fault/restart is
independent of alarm state. Initial RF support is NFC-A only. A valid physical
identifier is admitted through `submit_physical_tag` and reaches the same
`AlarmCore::handle_tag` authorization path as development simulation; it cannot
directly stop audio. See
`docs/milestone-5.md` for exact build and physical acceptance steps. Replace the
pending rows only with reproducible evidence and record whether each physical
result was user-reported or agent-observed.

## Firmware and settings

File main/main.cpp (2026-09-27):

#include <cinttypes>
#include "sdkconfig.h"
#include "esp_chip_info.h"
#include "esp_flash.h"
#include "esp_heap_caps.h"
#include "esp_log.h"
#include "esp_psram.h"
#include "esp_system.h"
#include "esp_timer.h"
#include "freertos/FreeRTOS.h"
#include "freertos/task.h"
#include "bringup.hpp"
#include "nvs_storage.hpp"

#if !CONFIG_IDF_TARGET_ESP32S3 || !CONFIG_ESPTOOLPY_OCT_FLASH || !CONFIG_SPIRAM_MODE_OCT
#error "This firmware requires ESP32-S3 with octal flash and octal PSRAM"
#endif
#if defined(CONFIG_CLOCK_SIMULATED_NFC) && !defined(CONFIG_CLOCK_DEVELOPMENT_BUILD)
#error "Simulated NFC is forbidden in production"
#endif

extern "C" void app_main()
{
    constexpr auto tag = "clock";
    ESP_LOGI(tag, "NFC alarm clock milestone 5 / 0.5.0 / IDF %s", esp_get_idf_version());
#ifdef CONFIG_CLOCK_DEVELOPMENT_BUILD
    ESP_LOGW(tag, "DEVELOPMENT BUILD - not production firmware");
#else
    ESP_LOGI(tag, "PRODUCTION profile: simulated dismissal disabled");
#endif
#ifdef CONFIG_CLOCK_SIMULATED_NFC
    ESP_LOGW(tag, "SIMULATED NFC selected; development tag injection enabled");
#endif
    esp_chip_info_t chip{};
    esp_chip_info(&chip);
    ESP_LOGI(tag, "cores=%u revision=%u reset_reason=%d", chip.cores, chip.revision,
             static_cast<int>(esp_reset_reason()));
    uint32_t flash_bytes = 0;
    const esp_err_t flash_result = esp_flash_get_size(nullptr, &flash_bytes);
    const size_t psram_bytes = esp_psram_is_initialized() ? esp_psram_get_size() : 0;
    const bool memory_ok = flash_result == ESP_OK && flash_bytes == 32U * 1024 * 1024
                          && psram_bytes == 16U * 1024 * 1024;
    ESP_LOGI(tag, "flash=%" PRIu32 " bytes (%s), PSRAM=%zu bytes", flash_bytes,
             esp_err_to_name(flash_result), psram_bytes);
    if (!memory_ok) {
        ESP_LOGE(tag, "MEMORY MISMATCH: expected 33554432 flash / 16777216 PSRAM bytes");
    }
    const auto nvs = clock_storage::initialize_nvs();
    ESP_LOGI(tag, "NVS initialization: %s (%s; never auto-erased)",
             nvs.ready() ? "READY" : "FAULT", esp_err_to_name(nvs.error));
    ESP_LOGW(tag, "Milestone 5 PN7160 integration under physical validation");
    start_bringup();
    while (true) {
        ESP_LOGI(tag, "uptime=%" PRIi64 "s memory=%s internal_free=%zu psram_free=%zu",
                 esp_timer_get_time() / 1000000, memory_ok ? "OK" : "FAULT",
                 heap_caps_get_free_size(MALLOC_CAP_INTERNAL | MALLOC_CAP_8BIT),
                 heap_caps_get_free_size(MALLOC_CAP_SPIRAM));
        vTaskDelay(pdMS_TO_TICKS(10000));
    }
}

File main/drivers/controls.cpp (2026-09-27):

#include "controls.hpp"
#include "board.hpp"
#include <initializer_list>
#include "esp_log.h"
#include "esp_rom_sys.h"
#include "freertos/task.h"
namespace clock_hw {
namespace {
uint32_t be32(const uint8_t* v) { return uint32_t(v[0]) << 24 | uint32_t(v[1]) << 16 | uint32_t(v[2]) << 8 | v[3]; }
}
esp_err_t Controls::init_buttons() {
    gpio_config_t cfg{};
    cfg.pin_bit_mask = (1ULL << button1) | (1ULL << button2);
    cfg.mode = GPIO_MODE_INPUT; cfg.pull_up_en = GPIO_PULLUP_ENABLE;
    const auto err = gpio_config(&cfg);
    gpio_ready_ = err == ESP_OK;
    return err;
}
bool Controls::read_seesaw(uint8_t base, uint8_t reg, uint8_t* data, size_t size) {
    const uint8_t command[]{base,reg};
    if (bus_.write(encoder, command, 2) != ESP_OK) return false;
    // seesaw needs a STOP + processing delay before the separate read. Bus is
    // unlocked here. All seesaw access remains owned by this peripheral task.
    esp_rom_delay_us(250);
    return bus_.read(encoder, data, size) == ESP_OK;
}
bool Controls::init_encoder() {
    if (bus_.probe(encoder) != ESP_OK) return false;
    uint8_t id = 0, version[4]{};
    if (!read_seesaw(0,1,&id,1) || !read_seesaw(0,2,version,4)) return false;
    if (id != 0x55 && (id < 0x84 || id > 0x89)) return false;
    const unsigned product = be32(version) >> 16;
    // 5880 is the preassembled 4991 breakout; verify the firmware product ID.
    if (product != 4991) { ESP_LOGE("encoder", "unexpected seesaw product %u", product); return false; }
    for (uint8_t reg : {uint8_t(0x03),uint8_t(0x0b),uint8_t(0x05)}) {
        const uint8_t command[]{1,reg,1,0,0,0}; // switch is seesaw GPIO24
        if (bus_.write(encoder,command,sizeof(command)) != ESP_OK) return false;
    }
    uint8_t position[4]{};
    if (!read_seesaw(0x11,0x30,position,4)) return false;
    position_ = be32(position);
    buttons_[2] = {};
    ESP_LOGI("encoder", "seesaw product=%u hardware=0x%02x ready", product,id);
    return true;
}
ControlEvents Controls::poll(int64_t now_ms) {
    ControlEvents events;
    if (gpio_ready_) {
        if (buttons_[0].update(!gpio_get_level(button1),now_ms)) {
            events.button1 = buttons_[0].pressed();
            ESP_LOGI("controls", "button1 %s", events.button1 ? "pressed" : "released");
        }
        if (buttons_[1].update(!gpio_get_level(button2),now_ms)) {
            events.button2 = buttons_[1].pressed();
            ESP_LOGI("controls", "button2 %s", events.button2 ? "pressed" : "released");
        }
    }
    if (!online_) {
        if (now_ms < retry_at_) return events;
        online_ = init_encoder(); retry_at_ = now_ms + 5000;
        if (!online_) return events;
    }
    uint8_t position[4]{}, pins[4]{};
    if (!read_seesaw(0x11,0x30,position,4) || !read_seesaw(1,4,pins,4)) {
        online_ = false; retry_at_ = now_ms + 5000;
        ESP_LOGW("encoder", "read failed; retry in 5s"); return events;
    }
    // Preassembled 5880 encoder is reversed relative to a loose encoder.
    events.turn = -clock_core::encoder_delta(position_,be32(position));
    position_ = be32(position);
    if (buttons_[2].update(!(be32(pins) & (1U << 24)), now_ms)) {
        events.encoder_button = buttons_[2].pressed();
        ESP_LOGI("controls", "encoder button %s", events.encoder_button ? "pressed" : "released");
    }
    return events;
}
}

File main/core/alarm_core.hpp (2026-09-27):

#pragma once
#include "calendar.hpp"
#include <array>
#include <cstddef>
#include <cstdint>

namespace clock_core {
constexpr size_t max_alarms = 8;
constexpr size_t max_tags = 8;
constexpr size_t max_tag_bytes = 10;
constexpr size_t max_active = 8;
constexpr size_t max_history = 32;
constexpr int64_t missed_window_seconds = 5 * 60;

enum class TimeZone : uint8_t { utc, america_los_angeles };
const char* timezone_name(TimeZone zone);
bool parse_timezone(const char* text, TimeZone& zone);

struct LocalTime {
    DateTime value{};
    int offset_minutes = 0;
    bool daylight = false;
};
LocalTime to_local(int64_t utc_seconds, TimeZone zone);

struct TagId {
    uint8_t size = 0;
    std::array<uint8_t,max_tag_bytes> bytes{};
};
bool parse_tag(const char* text, TagId& tag);
bool same_tag(const TagId& left, const TagId& right);

struct AlarmDefinition {
    uint32_t id = 0;
    uint8_t hour = 0;
    uint8_t minute = 0;
    uint8_t weekdays = 0; // Bit 0=Sunday through bit 6=Saturday.
    bool enabled = false;
};

struct Occurrence {
    uint32_t alarm_id = 0;
    int32_t local_date = 0; // YYYYMMDD; stable across UTC offset changes.
    int64_t due_utc = 0;
};

struct PersistentAlarmState {
    uint32_t schema = 1;
    bool cursor_valid = false;
    int64_t cursor_minute_utc = 0;
    std::array<Occurrence,max_active> active{};
    uint8_t active_count = 0;
    std::array<TagId,max_tags> authorized_tags{};
    uint8_t authorized_count = 0;
    std::array<Occurrence,max_history> history{};
    uint8_t history_count = 0;
    uint32_t missed_count = 0;
    uint32_t skipped_count = 0;
};

enum class LoadResult { empty, loaded, fault };
class AlarmStorage {
public:
    virtual ~AlarmStorage() = default;
    virtual LoadResult load(PersistentAlarmState& state) = 0;
    virtual bool save(const PersistentAlarmState& state) = 0;
};

enum class AlarmEvent {
    none,
    initialized,
    triggered,
    missed,
    skipped,
    dismissed,
    unknown_tag,
    authorized_while_idle,
    rejected_while_ringing,
    invalid,
    storage_fault
};
struct AlarmDecision {
    AlarmEvent event = AlarmEvent::none;
    bool start_audio = false;
    bool stop_audio = false;
};
struct AlarmView {
    bool initialized = false;
    bool ringing = false;
    bool storage_fault = false;
    uint8_t active_count = 0;
    uint32_t missed_count = 0;
    uint32_t skipped_count = 0;
    TimeZone zone = TimeZone::utc;
};

class AlarmCore {
public:
    explicit AlarmCore(AlarmStorage& storage) : storage_(storage) {}
    AlarmDecision initialize();
    bool restore_configuration(TimeZone zone, const AlarmDefinition* alarms, uint8_t alarm_count,
                               const TagId* tags, uint8_t tag_count);
    bool replace_configuration(TimeZone zone, const AlarmDefinition* alarms, uint8_t alarm_count,
                               const TagId* tags, uint8_t tag_count);
    bool upsert_alarm(const AlarmDefinition& alarm);
    bool set_timezone(TimeZone zone);
    bool enroll(const TagId& tag);
    AlarmDecision evaluate(bool time_valid, int64_t now_utc);
    AlarmDecision handle_tag(const TagId& tag);
    AlarmDecision development_trigger(int64_t now_utc);
    AlarmView view() const;
    bool ringing() const { return state_.active_count != 0; }
    bool mutations_allowed() const { return initialized_ && !recovery_blocked_ && !ringing(); }
private:
    bool valid_persistent(const PersistentAlarmState& state) const;
    bool commit(const PersistentAlarmState& state);
    bool history_contains(const PersistentAlarmState& state, const Occurrence& occurrence) const;
    void add_history(PersistentAlarmState& state, const Occurrence& occurrence) const;
    bool active_contains(const PersistentAlarmState& state, const Occurrence& occurrence) const;
    void capture_authorization(PersistentAlarmState& state) const;
    bool install_configuration(TimeZone zone, const AlarmDefinition* alarms, uint8_t alarm_count,
                               const TagId* tags, uint8_t tag_count);
    AlarmStorage& storage_;
    PersistentAlarmState state_{};
    std::array<AlarmDefinition,max_alarms> alarms_{};
    uint8_t alarm_count_ = 0;
    std::array<TagId,max_tags> enrolled_{};
    uint8_t enrolled_count_ = 0;
    TimeZone zone_ = TimeZone::utc;
    bool initialized_ = false;
    bool storage_fault_ = false;
    bool recovery_blocked_ = false;
    bool evaluated_cursor_valid_ = false;
    int64_t evaluated_cursor_minute_utc_ = 0;
};
}

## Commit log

2026-09-19 Add first buildable ESP32-S3 alarm clock firmware milestone
    [breadboard-prototype.kicad_pcb, breadboard-prototype.kicad_sch, partitions.csv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]
2026-09-20 kicad update
    [breadboard-prototype.kicad_pcb, breadboard-prototype.kicad_sch]
